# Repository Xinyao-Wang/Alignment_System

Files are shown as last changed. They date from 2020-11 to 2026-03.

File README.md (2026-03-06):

# Alignment System

Mechanical design project for a **laser alignment system** intended to precisely point a laser in a predetermined direction during assembly, with a removable adjustment mechanism and a locking mechanism to hold the final position. The repository currently contains four concept prototypes plus the final design report and presentation.

## Overview

This project was developed as **AS-1** for **ME175C**. The final design uses:

- a **two-axis adjustment mechanism**
- a **ball-joint-based fixing mechanism**
- **gear-driven angular adjustment**
- a **threaded-bolt mechanism** for controlled extension and shortening

The design targets precise manual alignment for applications where pointing accuracy matters, such as UAV-mounted systems and other directional devices.

## Design Requirements

The system was designed to satisfy the following requirements:

- **Adjustment range:** ±10°
- **Adjustment accuracy:** 0.2° to 0.4°
- **Mass:** under 500 g
- **Control dimensions:** 2-axis (roll and pitch)
- **Working temperature:** 0°C to 40°C
- **System size:** about 200–220 mm scale

These requirements and verification targets are documented in the final report and presentation.

## Final Design

The final concept combines an **adjustment mechanism** and a **fixing mechanism**:

- The **adjustment mechanism** uses an upper threaded adjustment path and a lower worm-gear path to control the laser orientation.
- The **fixing mechanism** uses a **ball joint** and locking structure to hold the aligned laser in place once adjustment is complete.
- After alignment, the adjustment structure can be removed while preserving the final laser direction.

## Verification Summary

The design was evaluated using **SolidWorks modeling** and **MATLAB analysis**.

### Accuracy
The report verifies that the design can achieve the required fine angular resolution, with estimated adjustment accuracy below **0.4°**, meeting the design target.

### Range of motion
The calculated movement range reaches about **10.36°**, satisfying the required **10°** alignment range.

## Repository Contents

This repository includes the following main items:

- `Prototype 1/`
- `Prototype 2/`
- `Prototype 3/`
- `Prototype 4/`
- `AS-1 Final Design Report.pdf`
- `AS-1 Final Presentation.pdf` 

## Design Process

Four concept directions were explored before selecting the final design:

1. detachable mechanical-arm-based alignment
2. double-gear alignment with fixture system
3. ball-joint platform with perpendicular link adjustments
4. three-bolt height-adjustment platform

A decision matrix was then used to compare concepts on criteria such as weight, simplicity, safety, efficiency, precision, and ease of operation.

## Manufacturing Notes

The project includes component-level design for manufacturability, with parts made from materials such as:

- acetal rod
- UHMW sheet
- mild steel
- standard mechanical hardware

Detailed part and assembly drawings are included in the final report appendix.

## Files

- **Final Design Report:** complete design description, requirements, concept evaluation, verification, MATLAB analysis, and drawings
- **Final Presentation:** concise summary of the project scope, concepts, final design, and validation
- **Prototype folders:** concept development files for the four design directions

## Tools Used

- **SolidWorks** for CAD modeling and design visualization
- **MATLAB** for range and adjustment analysis
- standard mechanical design and manufacturability methods based on the project workflow described in the report and presentation.

## Authors

- Dongwei Li
- Xinyao Wang
- Shi Cheng
- Deng Pan

## Course Information

**Course:** ME175C  
**Team:** AS-1  
**Project:** Alignment System  
**Date:** June 2020

## Notes

This repository serves as an archive of the project’s concept development, final design documentation, and presentation materials.

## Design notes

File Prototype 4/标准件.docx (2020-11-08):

蜗轮蜗杆：

https://www.ebay.com/itm/0-5-Modulus-20-to-60-Teeth-Worm-Gear-and-Shaft-Drive-Gearbox-Select-Size/302516360044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

涡轮：worm gear

https://www.mcmaster.com/57545K513

蜗杆：worm

https://www.mcmaster.com/57545K527

键：rounded machine key

https://www.mcmaster.com/95053A135

螺杆 screw

https://www.mcmaster.com/91310A151

螺帽 nut

https://www.mcmaster.com/90592A034

底座固定螺栓 screw

https://www.mcmaster.com/91310A332

底座柱固定螺栓

https://www.mcmaster.com/91310A332

球关节 ball knob

https://www.mcmaster.com/6045K32

球关节螺栓 screw

https://www.mcmaster.com/92620A204

中间棒 rod /导轨杆

https://www.mcmaster.com/8497K371

轴承 ball bearing

https://www.mcmaster.com/5972K91

上面的外壳 steel round tube

https://www.mcmaster.com/7767t271

导轨螺栓 socket head screw

https://www.mcmaster.com/90332A112

导轨螺帽 nut

https://www.mcmaster.com/96537A120

底板

https://www.mcmaster.com/4296A28

套筒组件螺栓

https://www.mcmaster.com/91290A231

卡簧

https://www.mcmaster.com/97431A310

内垫圈

https://www.mcmaster.com/90214A518

外垫片

https://www.mcmaster.com/90214A536

弹簧

https://www.mcmaster.com/9657K424

缓冲垫片

https://www.mcmaster.com/93650A110

金属垫圈

https://www.mcmaster.com/92141A009

peel shim

https://www.mcmaster.com/9574K76-9574K76

Base Adjustment Bolt Nut

https://www.mcmaster.com/96194A101

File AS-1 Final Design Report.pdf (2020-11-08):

AS-1

## THE DESIGN OF LASER ALIGNMENT SYSTEM

Dongwei Li, Xinyao Wang, Shi Cheng, Deng Pan

Course Number: ME175C

Team Number: AS-1

Instructor: Prof. Dinsmore

Project: Alignment System

Date: 06/08/2020

Executive Summary

In some specific situations, such as distant communications or UAV precise

positioning. Antenna or other related devices itself should be positioned precisely to reduce

the final total error of the product. So, our goal is to design and construct a device which

will allow a laser to be precisely adjusted to an UAV in the process of assemble and, once

it is in the final position, will hold the laser in place. We design a device which can rotate

the adjusting bolts to control the threaded rod to achieve our requirements. We first

determine the system’s some of the most basic requirements, through several iterations, we

get the current model, then verified the device’s adjustment accuracy and range by

modeling and analysis by Solidworks and MATLAB. Up to now, we have completed all

the design process. Under the assumption that the minimum adjustment angle of hand is 4

degree, we get the result that the accuracy is between 0.2-0.4 degree, which meets the

requirement we set.

Table of Contents

### 4.1 The Input, Output and Parameters set by our Simplified Model……11

### 1. Introduction

Alignment systems are widely used, from Mars probes to drones. Because of the

highly directional nature of these high-performance systems, even small misalignments in

the system can prevent the receiver from seeing the signal. Our goal is to design and

construct a device which will allow a laser to be precisely adjusted to an UAV in the

process of assemble and, once it is in the final position, will hold the laser in place. We set

the adjustment range is 10°, adjustment accuracy is 0.3°, two axis control and total mass

less than 500g. In this article, we introduce the detailed device information, demonstration

process, model building and validation and detailed component and assembly drawings.

### 2. Problem Statement

Alignment systems are widely used, from Mars probes to drones. It is especially

important to precisely align the interface and related fixtures. Our group mainly considers

the alignment system to fix a laser pen on the joint surface and point it in any predetermined

direction.

### 2.1 System Requirements

In order to increase generality, we set our system’s size about 200mm, and because

of our project is a high precision device, we consider the adjustment range and accuracy

are the main requirements of our design, thus we set the adjustment range is 20°, adjustment

accuracy is about 0.2°---0.4°. In order to reduce the impact on the performance of the drone

and increase reliability, we decide the fixing system total mass is less than 500g. Our main

task is to control its pointing direction; thus, the effect of laser pen rotate around the long

axis can be ignored.

### 3. Design Solution

The mechanical structure we finally designed consists of two parts, adjusting

mechanism and fixing mechanism (Fig. 1).

Adjustment range | ±10°
Adjustment accuracy | 0.2°~0.4°
System mass | <500g
System size | ≈200mm
Working temperature | 0℃-40℃
Control dimensions | 2-axis (roll pitch)

Table.1 System requirements

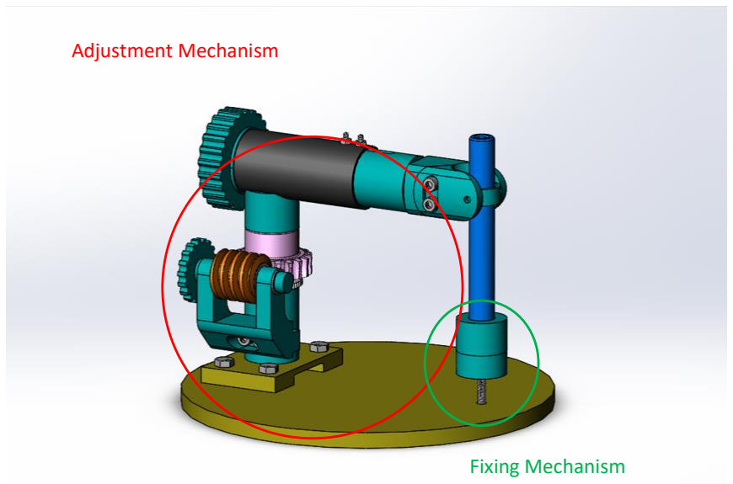
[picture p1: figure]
Adjustment Mechanism; Fixing Mechanism

Fig. 1 Adjustment mechanism and Fixing mechanism

### 3.1 Adjustment Mechanism

The Fig. 2 shows the name of key components, an adjusting bolt and threaded nut

are to control the vertical extension and shortening of the robot arm. Another adjusting bolt

and worm also have gear to control the rotation of the robot arm in the horizontal direction.

The sleeve could move along the laser pen and rotate to satisfy any angle, so that these two

bolts could control the laser pen move in a fan-shaped plane, and point to any point in this

area.

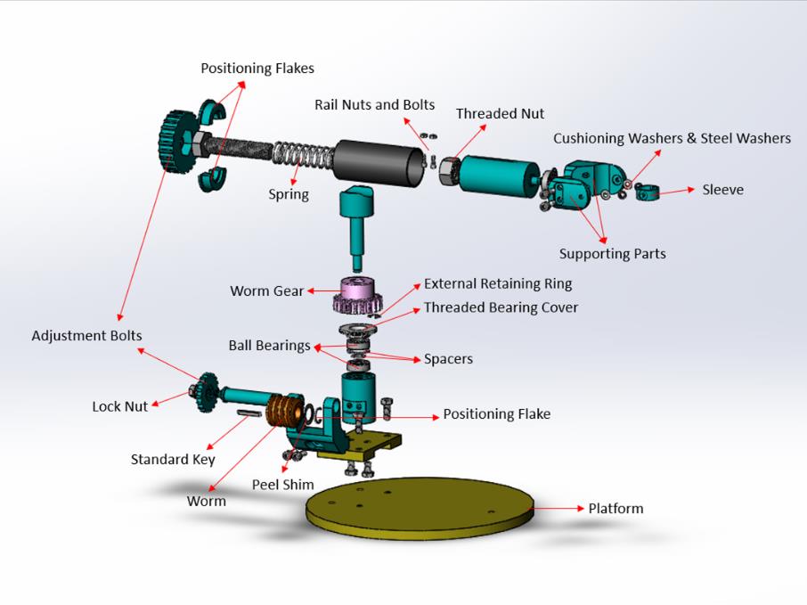
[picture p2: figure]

Fig. 2 Key components of adjustment mechanism

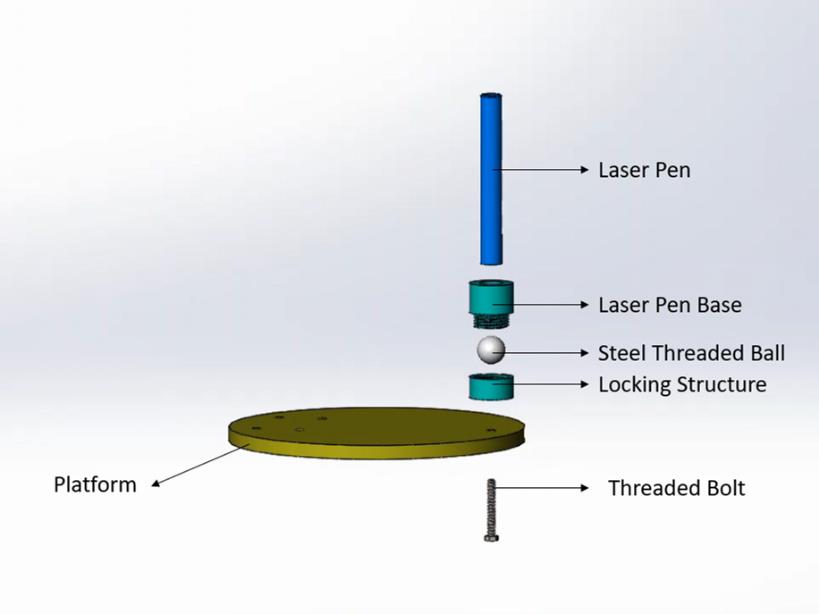
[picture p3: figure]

Fig. 3 Components of fixing mechanism

### 3.2 Fixing Mechanism

The fixing mechanism is mainly composed of steel ball, locking structure, threaded

bolt, as shown in Fig. 3. And the threaded bolt is used to fix the ball joint on the platform,

the structure is similar to the ball joint on tripod and phone holder on vehicle, a high friction

will be produced by pressure, and stable fix the ball joint.

The operator only needs to handle these two adjustment bolts to adjust the

mechanical arm to extend or shorten in vertical direction and to rotate the mechanical arm

in the horizontal direction. The movement of the laser is driven by the movement of the

mechanical arm. When moving to the specified position, user can tighten the ball joint to

fix it. Finally, we will dismantle the adjustment mechanism and keep aligned laser.

### 3.3 Function and Material of Components

Some of the parts that make up our mechanical device are standard parts purchased

directly. What we introduce below are that we need to purchase materials and manufacture.

The parts in Figures 4 to 17 are made by Acetal Rod. They are manufactured by

CNC milling machine and CNC lathe according to the parts drawing. The holes on the

parts can be drilled directly by laser drilling technology or punching machine.

Adjustment knob is a handle part to fix the bolt into its hexagon hole; the base

adjustment knob is also a handle part for worm and worm gear, it could be threaded into

the rod and fixed by locking nut; the base adjustment rod could connect knob and worm,

there are two way threads: left and right, which could ensure the locking nut will not fall

off after adjustment.

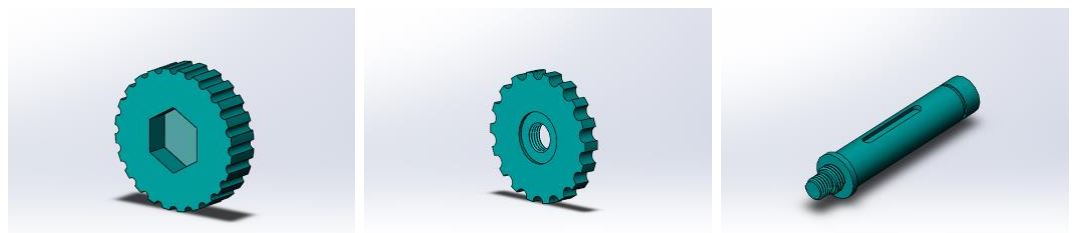
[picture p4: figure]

Fig. 4 Adjustment knob | Fig. 5 Base adjustment knob | Fig. 6 Base adjustment rod

Base rod is a basic part, which could connect base, top parts and worm part, there

are four threaded holes and a deep hole for two ball bearings; laser pen base could hold the

laser pen and the threaded ball, it could work with the nut for threaded ball together to

produce enough friction to fix the ball joint.

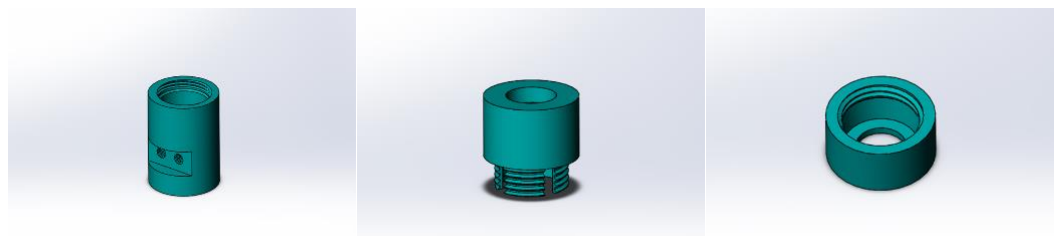
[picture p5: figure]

Positioning flake is a supporting part for adjustment bolt, two flakes could limit the

axial movement of bolt during the adjustment, and another step could support the spring;

the rail rod is working as a mechanical arm, which could fix the adjustment nut into its

hexagon hole, and the groove could limit the rotation during the adjustment, on the other

side, the small rod could fix the ball bearing and support the sleeve part; the supporting rod

for shell is a supporting part to connect base rod and shell.

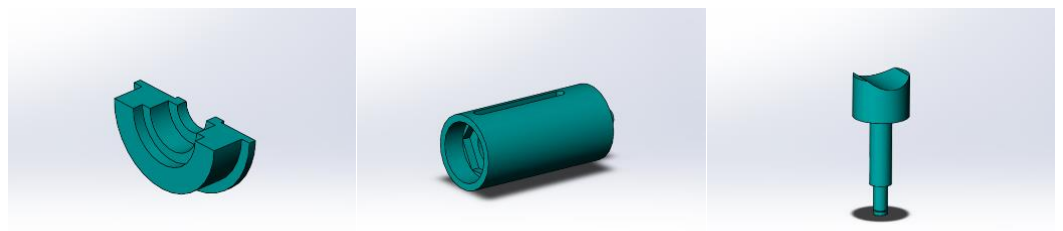
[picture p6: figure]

These three are components of sleeve parts: two supporting parts and a sleeve. The

supporting parts could contain a ball bearing which could provide low friction during

rotation, and also could hold the sleeve and ensure its movement; the sleeve has three

“points” to reduce friction between laser pen.

Fig. 7 Base rod | Fig. 8 Laser pen base | Fig. 9 Nut for threaded ball
Fig. 10 Positioning flake | Fig. 11 Rail rod | Fig. 12 supporting rod for shell

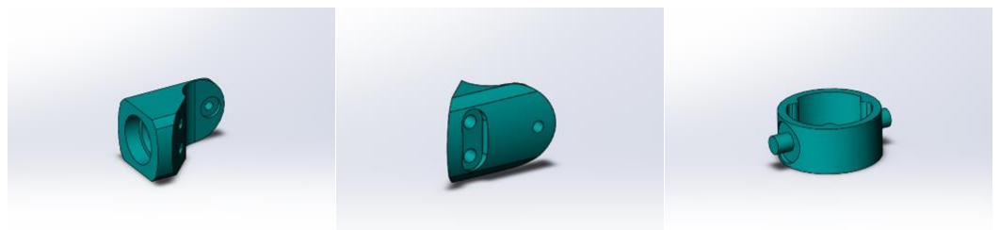
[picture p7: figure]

The supporting part for worm could be fixed on the base rod by two screws, and it

could support the worm and provide enough force to avoid movement during adjustment;

the threaded bearing cover could be threaded into the base rod, and fix the outer ring of the

top ball bearing to avoid loosening.

The parts in Fig. 18 and Fig. 19 are made of Slippery Black UHMW Sheet. They

are punched with a punching machine after being processed by a lathe. The base is a

connecting part to connect base rod and platform, which has six holes for screws, two are

to fix rod, four are to fix the platform; the platform is the supporting part for the adjustment

mechanism and the fixing mechanism, they will be fixed on it and cooperate.

Fig. 13 Supporting part 1 | Fig. 14 Supporting part 2 | Fig. 15 Sleeve

Fig. 16 Supporting part for worm

Fig. 17 Threaded
bearing cover

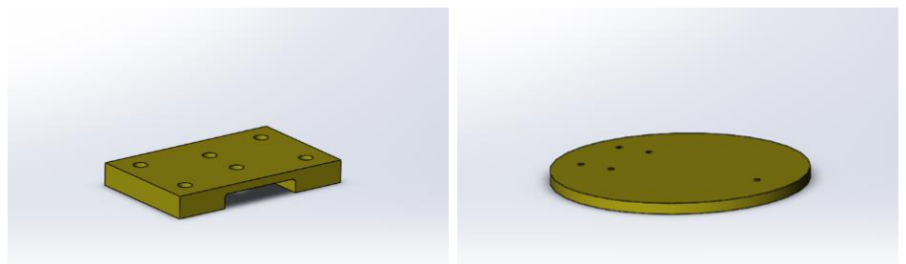
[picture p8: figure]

Fig. 18 Base | Fig. 19 Platform

The part shown Fig. 20 is made of mild steel. Just use a milling machine to make

two holes on the cylindrical material into the part shown on the CNC lathe. The shell is a

supporting part to hold rail rod and the bolt, the two holes are for rail screws and nuts, they

could be fixed into holes and work as guides.

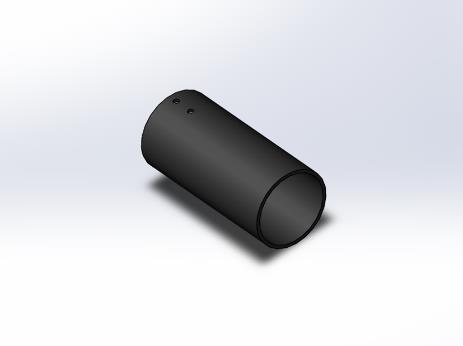
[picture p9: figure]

### 4. Design Verification

The purpose of our virtual prototype is to show the parts intuitively and omit the

shapes and dimensions that have no influence on the calculation. In the simplified model,

we only keep two pairs of gears, laser pen and necessary rotating parts. We use the center

point of the contact position between the sleeve and the laser pen to represent the laser

coordinates. It is used to analyze and verify whether (1) the accuracy and (2) the range of

the adjustment system designed by us meet the requirements. The position change of the

center point and the angle change of the laser pointer relative to the vertical state when the

two gears rotate respectively are calculated by MATLAB, which is used to check our

design.

Fig. 20 Shell

First, Fig. 21 shows our adjustment range. The shadow part represents the

maximum moving range of laser in our system. The range included in the circle represents

the range of movement we require.

### 4.1 The Input, Output and Parameters set by our Simplified Model

Fig. 22 and Fig. 23 show the radius parameters of the moving range and the actual

required range of the manipulator. Fig. 24 shows the length change of the manipulator.

And then we get:

Parameter (1): Radius of laser pen center (r): 16.75 mm

Parameter (2): Radius range of the system(R): 17.35 mm

Input (1): Change range of arm length(b): -17.35mm~17.35 mm

Fig. 21 Movement range

Fig. 22 Designed range | Fig. 23 Actual range | Fig. 24 Length variation of mechanical arm

Fig. 25 and Fig. 26 show the deflection angle of our robot arm and the deflection

angle of the laser pen based on the reference plane and line.

And then we get:

Parameter (3): Angle range of the system: -30°~30°

Parameter (4): Expected adjustment angle of laser pen: -10°~10°

Input (2): Angle range of the system(a): -30°~30°

Output (1): Deflection angle of laser pen(c): The value range of c should be greater than

be larger than -10°~10°

Fig. 27 shows the simplified length parameter of the part, which is convenient for

us to establish the coordinate system and other calculation and checking in the future.

And then we get:

Fig. 27 The simplified length parameter of the part

Fig. 25 Deflection angle of mechanical arm

Fig. 26 Deflection angle of laser pen

Parameter (5): Height from the Rod to the Ball Joint (H): 95 mm

Parameter (6): Radius from the base center to the pen (L): 140 mm

### 4.2 Verification of Adjustment Accuracy

First, as shown in Fig. 28, we divide our adjustment system into two parts: Part A

and Part B.

We need to adjust the gears in part a and part B respectively to adjust the deflection

range of the laser pen. Because the power of this structure is hand, it is hard to calculate

the accuracy of this system. Here we assume the minimum adjustment angle of hand is 4°.

The adjustment accuracy in part A is shown in Fig. 29.

Pitch of the Higher Adjusting Bolt: 2mm

Fig. 28 Divided adjustment system

Fig. 29 Part A

Minimum Adjustment Length of R: 2mm × (4°/360°) = 0.0222mm

Minimum Adjustment Angle of Bolt:

θ1 = 10° − arctan(

16.75 − 0.0222
95 ) = 0.0136°

θ2 = arctan(

0.0222
95 ) = 0.0134°

The adjustment accuracy in part B is shown in Fig. 30.

Speed Ratio: 20:1

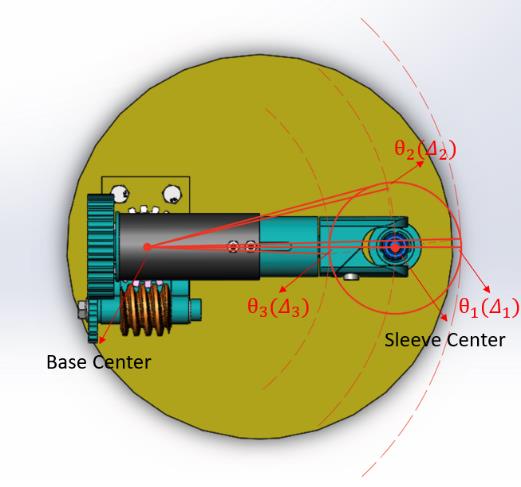
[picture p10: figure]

Angle per Pitch of the Worm Gear: 360°/20 = 18°

Worm Gear Minimum Rotation angle: 18° × (4°/360°) = 0.2°

Adjustment Angle of the Lower Gear: 0.18°

Minimum Adjustment Angle of Worm Gear:

√H² + R² = 96.47mm | (1)

Δ1 = (

0.2
360) × 2π(L + R) = 0.547mm | (2)

θ1 = arcsin (

0.547
96.47) = 0.325° | (3)

Δ2 ≈ (

0.2
360) × 2πL = 0.489mm | (4)

Fig. 30 Part B

θ2 = 10° − arctan(

16.75−0.489
95
) = 0.287 | (5)

Δ3 = (

0.2
360) × 2π(L − R) = 0.430mm | (6)

θ3 = arcsin (

0.430
96.47) = 0.256° | (7)

In part A and part B, our adjustment accuracy is less than 0.4°. And the adjustment

accuracy can meet our design requirement.

### 4.3 Verification of the Range of the Adjustment mechanism

Create a rectangular coordinate system, Fig. 31 as shown.

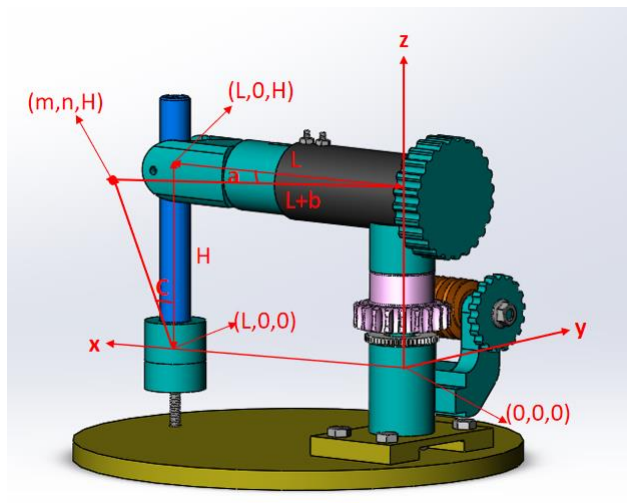
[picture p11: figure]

The center of the sleeve represents the position of the infrared light of the laser. The

initial coordinate is (L, 0, H). The changed coordinate of the laser adjusted to the specified

position is (m, n, H), and the deflection angle of the laser is c. The length of the manipulator

is L + b, and the deflection angle is a. Hence (m - L) is the change of x -coordinate and n

is the change of y-coordinate. And we can get：

m = (L + b) × cos(a); | (8)

Fig. 31 Coordinate system

n = (L + b) × sin(a); | (9)

c can be regarded as the angle between vector (m-L, n, H) and vector (0,0,1), then:

c = acos(

H
√(m−L)
2 | 2+n²+H²
); | (10)

Put in the parameters we set, corresponding to this part of the code in MATLAB,

as Fig. 32 shown.

Minimum Adjustment Length of R: 2mm × (4°/360°) = 0.0222mm

Worm Gear Minimum Rotation angle: 18° × (4°/360°) = 0.2°

Input(a): Angle range of the system: -30°—30°, unit angle:0.2°

Input(b): Change range of arm length: -17.35mm—17.35 mm unit length:0.0222mm

Then corresponding to this part of the code in MATLAB, Fig. 33 as shown.

In addition, substituting the input we set, Fig. 34 and 35 show the input data of a

and b.

Fig. 34 Input value of a

Fig. 32 Relational MATLAB code

Fig. 33 Input MATLAB code

a and b meet our input requirements. Finally, we take a, b as the input, m, n, c as

the output, and draw their images respectively, as Fig. 36, 37 and 38 shown. By observing

their images, we can get our range of motion.

Fig. 35 Input value of b

Fig. 36 Change of the reference point on the x-axis

Fig. 37 Change of the reference point on the y-axis

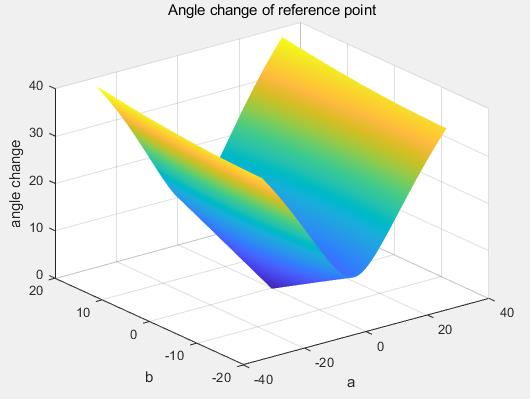
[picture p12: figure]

Fig. 38 Angel Change of the reference point

From figures above, we can see that the adjustment range (angle change) is about

10.36°, in the definition report, we set the requirement is 10°, thus the adjustment range

can meet our design requirement.

### 5. Approach to Solution

We first determine the system some of the most basic requirements, such as the

need to easy operation, simple structure and regulating mechanism can be removed, and

the method of using the 4-3-5, after the brainstorming, we finally came up with the total 4

kinds of structures.

### 5.1 Concept 1

The concept 1 has a detachable mechanical arm mounted on the joint surface (Fig.

39). It uses two bearings that are vertical in space to orient the alignment device’s direction.

If we fix the component on the mount surface directly, we cannot adjust its direction

conveniently. Therefore, a spherical pair is used to fix its position and adjust its direction

at the same time. On the adjusting device we extend the adjusting lever to get better

accuracy. In this solution, we can control the three supporting rods’ angles to make the

component point at presupposed direction. After the adjustment is completed, turn the

screws on the spherical pair to increase friction force between the shell and the ball. This

Fig. 39 Gear adjustment will fix it to point at the goal. Then remove the arm from mount surface to reduce the

weight of UAV.

### 5.2 Concept 2

The concept 2 is constructed with double-gear system as the alignment system and

connecting rod system as the fixture system (Fig. 40). For the alignment system, all the

components are connected with the frame while the frame is fixing on the UAV mount

with four bolts. By turning two meshing gears, the angles of x-z axis and y-z axis can be

changed to alignment. Using gears of different transmission ratios, the accuracy of angle

changing is determined and adjustable. For the fixture system, four rotating rods will allow

the angle changing of the laser and by fastening the screws of the joints and releasing the

buckle, the laser will be fixed after alignment.

### 5.3 Concept 3

The concept 3 has two platforms the UAV platform and the platform on which the

laser is placed are linked by a ball joint (Fig. 41, Fig. 42), which can ensure that the distance

between the centers of the two platforms remains the same, so that only the laser angle is

changed without changing the spatial position. Two four-strait structures are connected to

the laser platform perpendicularly to each other, and two joysticks are extended. First,

Fig. 40 Robotic arm adjustment adjust the two extending joysticks to adjust the vertical and horizontal rotations. After the

adjustment is completed, tighten the joint by tightening the ball joint nut, and use the

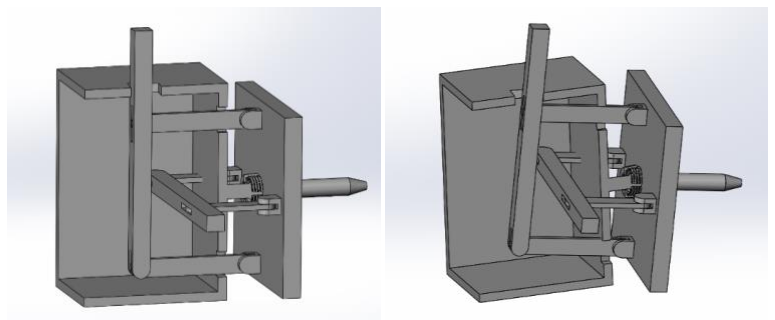
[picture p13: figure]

friction to fix the UAV platform and the laser platform.

### 5.4 Concept 4

The concept 4 is as shown in Fig. 43 and Fig. 44. Three bolt columns are fixed on

the surface of the UAV and pass through the sleeve on the plane equipped with laser. By

rotating the bolt, the three sleeves can move up and down in the vertical direction. The

three bolts are connected with the laser platform through the spherical joint, and three

sliders with an angle of 120 degrees are added into the laser platform to adapt to the

distance change between the platform and the bolts when the platform rotates. Therefore,

we can adjust the position of the triangle accurately by rotating three nuts to adjust the laser

direction.

Fig. 41 View 1 adjustment by 4 links | Fig. 42 View 2 adjustment by 4 links
Fig. 43 View 1 Height adjustment method | Fig. 44 View 2 Height adjustment method

### 5.5 Final Prototype

Finally, we used the decision matrices to evaluate whether these four systems meet

our requirements, including light weight, easy to operate, safe, simple structure, high

efficiency, and so on. The scoring content and results are shown in Table. 2.

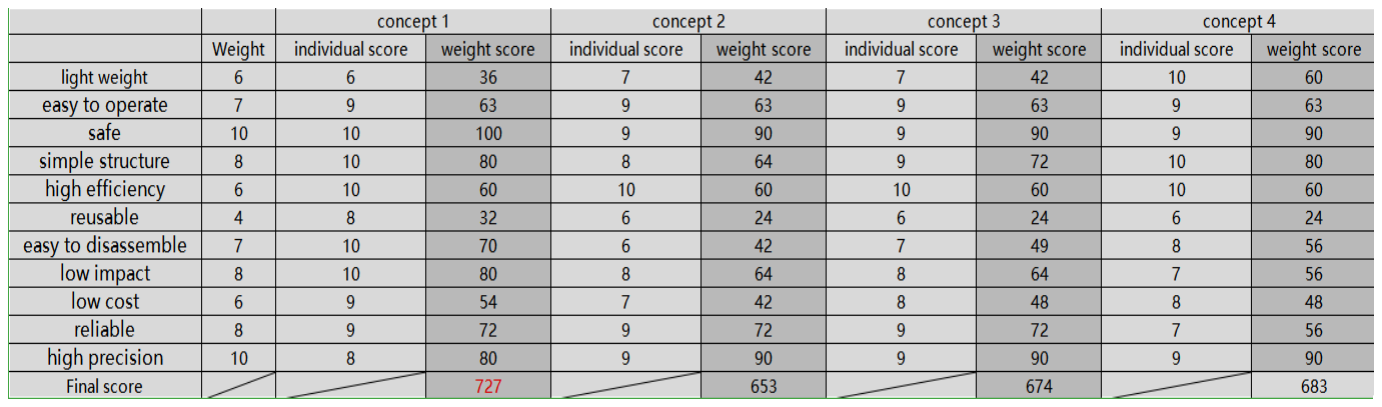
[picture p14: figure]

In the end, we get multiple designs to get the final design (Fig. 45), which is a

prototype to show our thoughts and the theory we used, so it is a little bit different from

the final design. It is easy to disassemble, easy to adjust and relatively simple in structure.

1. Laser movement controlled by robotic arm fixture
2. Fixing laser with ball joint
3. Gears can be used to control robotic arm deflection
4. We can use the bolt thread to control the elongation and shortening of the arm

Table.2 Decision matrices

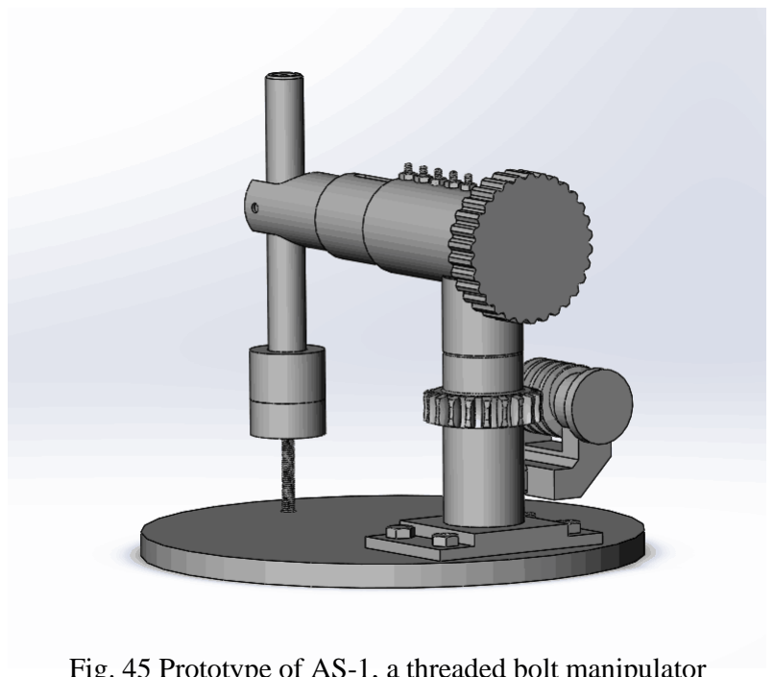
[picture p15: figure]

Fig. 45 Prototype of AS-1, a threaded bolt manipulator

It fully meets the specifications of the problem statement. As well it is easy to

manufacture.

### 6. Conclusions and Recommendations

So far, the proposed design meets all the requirements in the problem definition

and it is the most optimum plan considering the cost, the materials, and other aspects in

this project. However, if there is another project with different requirements or there are

better choices of the materials found, here are the recommendations.

For the design of the adjusting bolt, since the low yield of the alignment systems,

step cut will make sure the high precision which is applied in this project.

Once it comes to special cases that the yield become high, considering the cost of

step cut, washers should be the better choice which can fit the basic function of reducing

connecting area and save much money as well. But the precision will be lower than our

design

For the design of the supporting part, if there are screws with high friction or more

reliable design, the number of screws can be reduced by one.

## References

Appendices

MATLAB code:

clear

clear all

x=linspace(-30,30,241);

y=linspace(-17.35,17.35,1249);

[X,Y] = meshgrid(x,y);

m=(140+Y).*cos(X/180*pi);

n=(140+Y).*sin(X/180*pi);

k=m-140;

Z=acos(95./sqrt(k.*k+n.*n+95^2))*180/pi;

Z=real(Z);

figure(1),mesh(X,Y,Z),view(3)

title('Angle change of reference point')

xlabel('x')

ylabel('y')

zlabel('angle change')

figure(2),mesh(X,Y,m),view(3)

title('Change of the reference point on the x-axis')

xlabel('x')

ylabel('y')

zlabel('Changes on x axis')

figure(3),mesh(X,Y,n),view(3)

title('Change of the reference point on the y-axis')

xlabel('x')

ylabel('y')

zlabel('Changes on y axis')

Part and Assembly Drawings

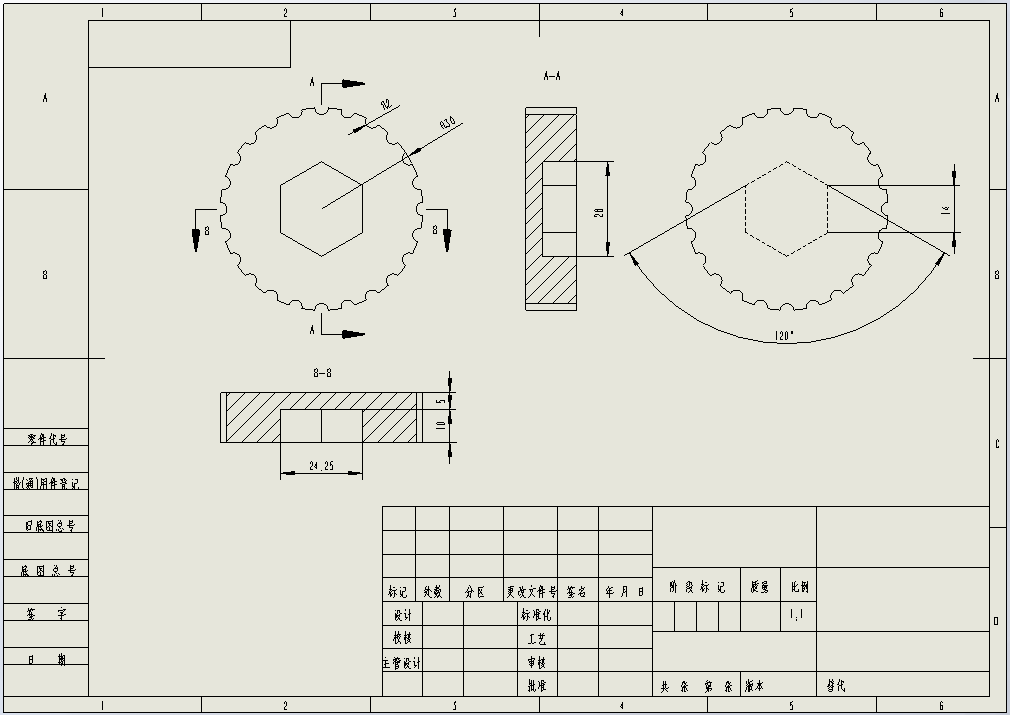
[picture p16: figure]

Fig. 46 the part drawing of adjusting knob

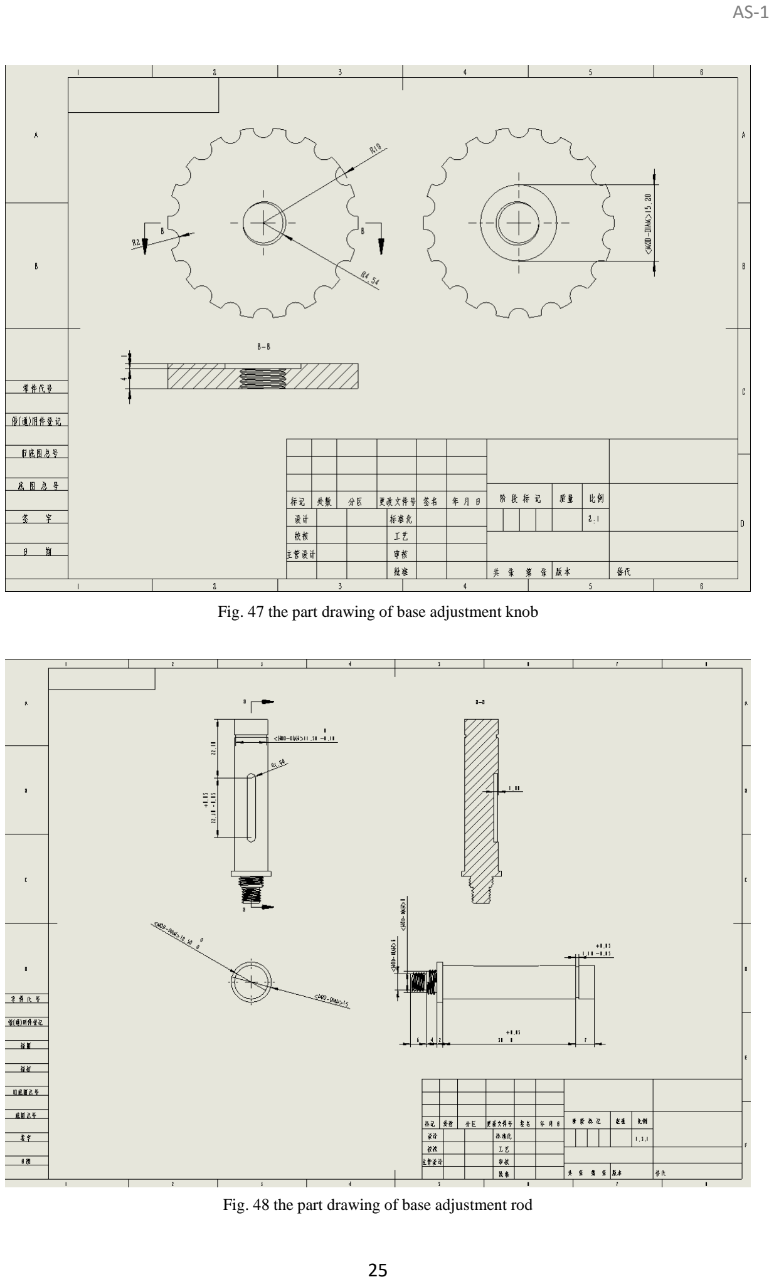
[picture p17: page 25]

Fig. 48 the part drawing of base adjustment rod

Fig. 47 the part drawing of base adjustment knob

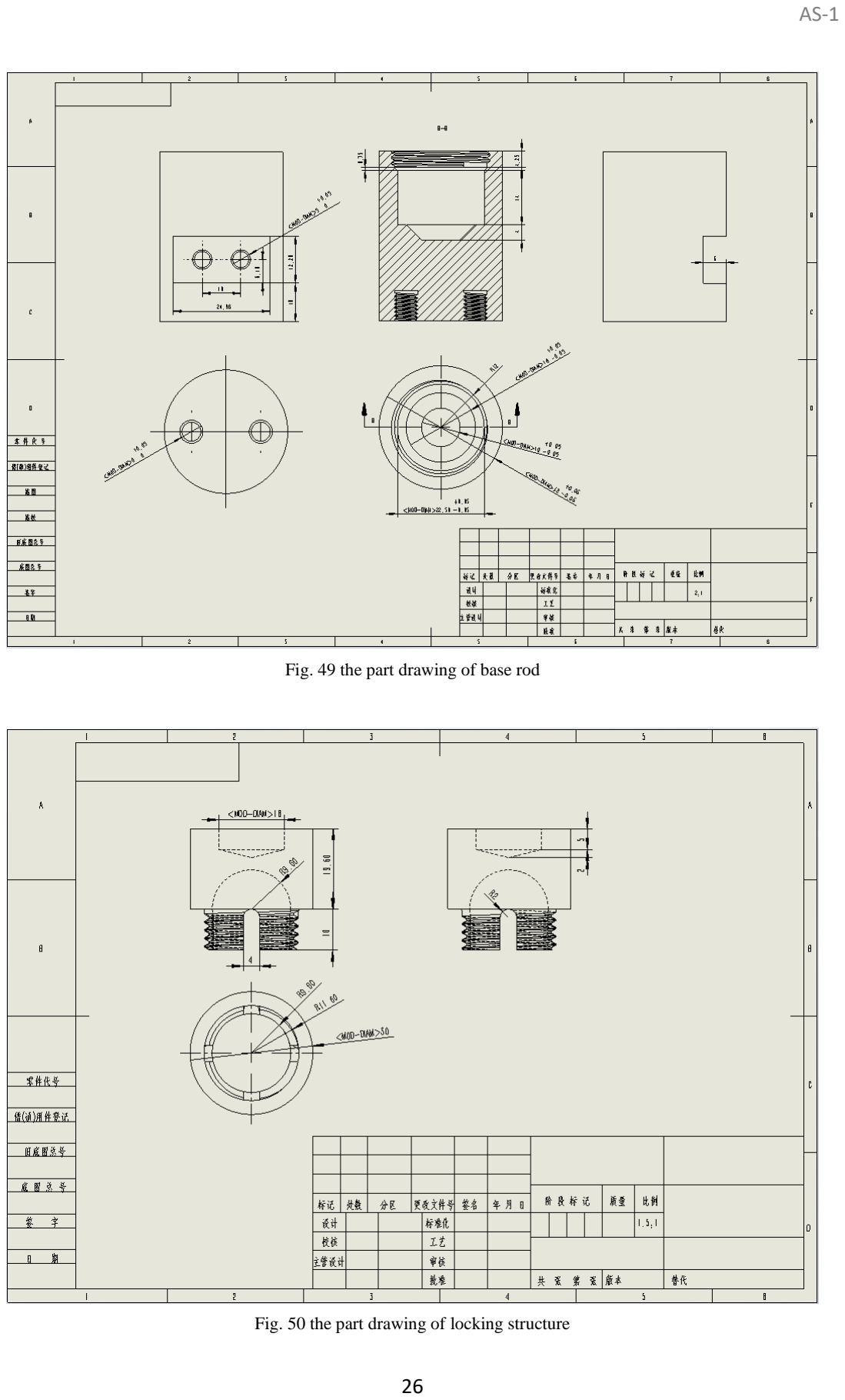
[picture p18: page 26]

Fig. 49 the part drawing of base rod

Fig. 50 the part drawing of locking structure

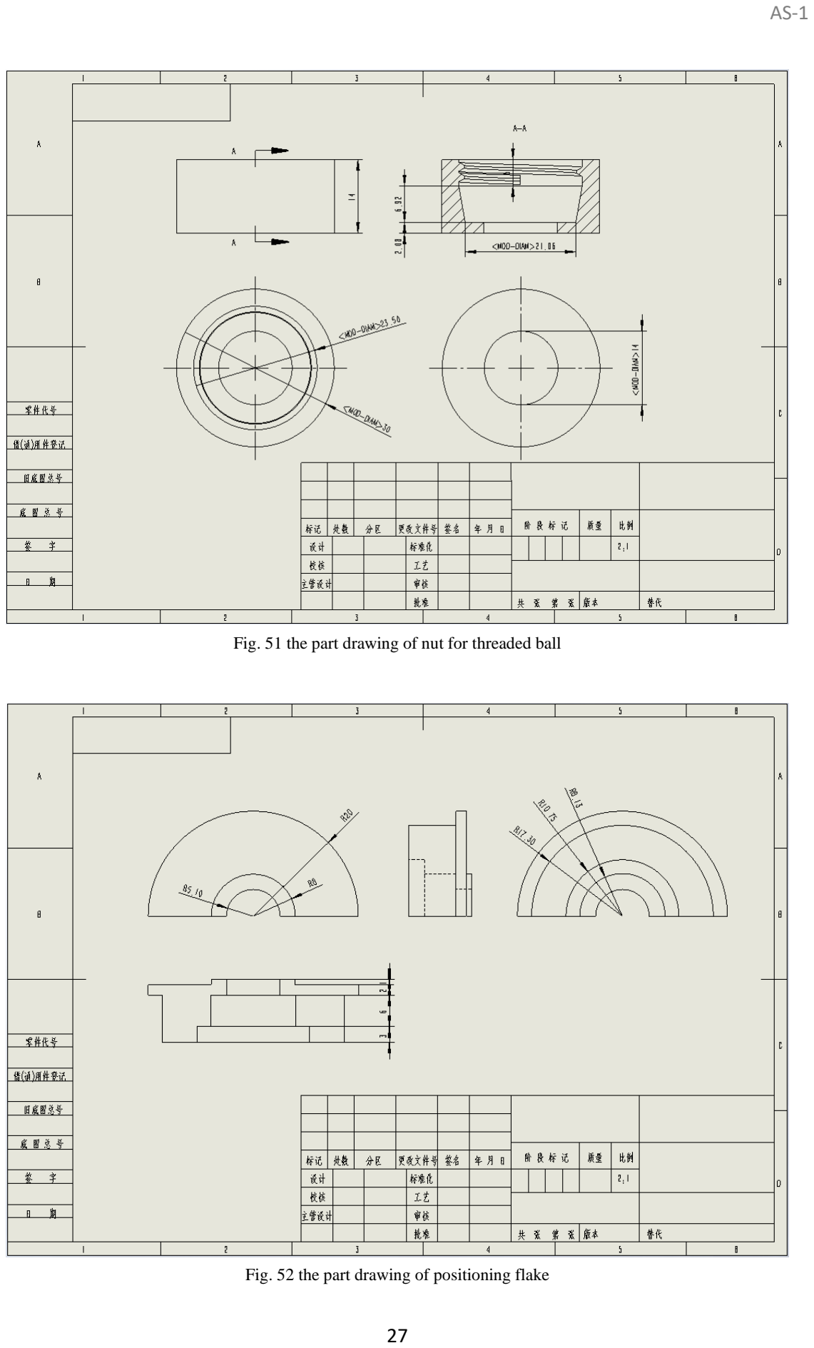
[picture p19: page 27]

Fig. 51 the part drawing of nut for threaded ball

Fig. 52 the part drawing of positioning flake

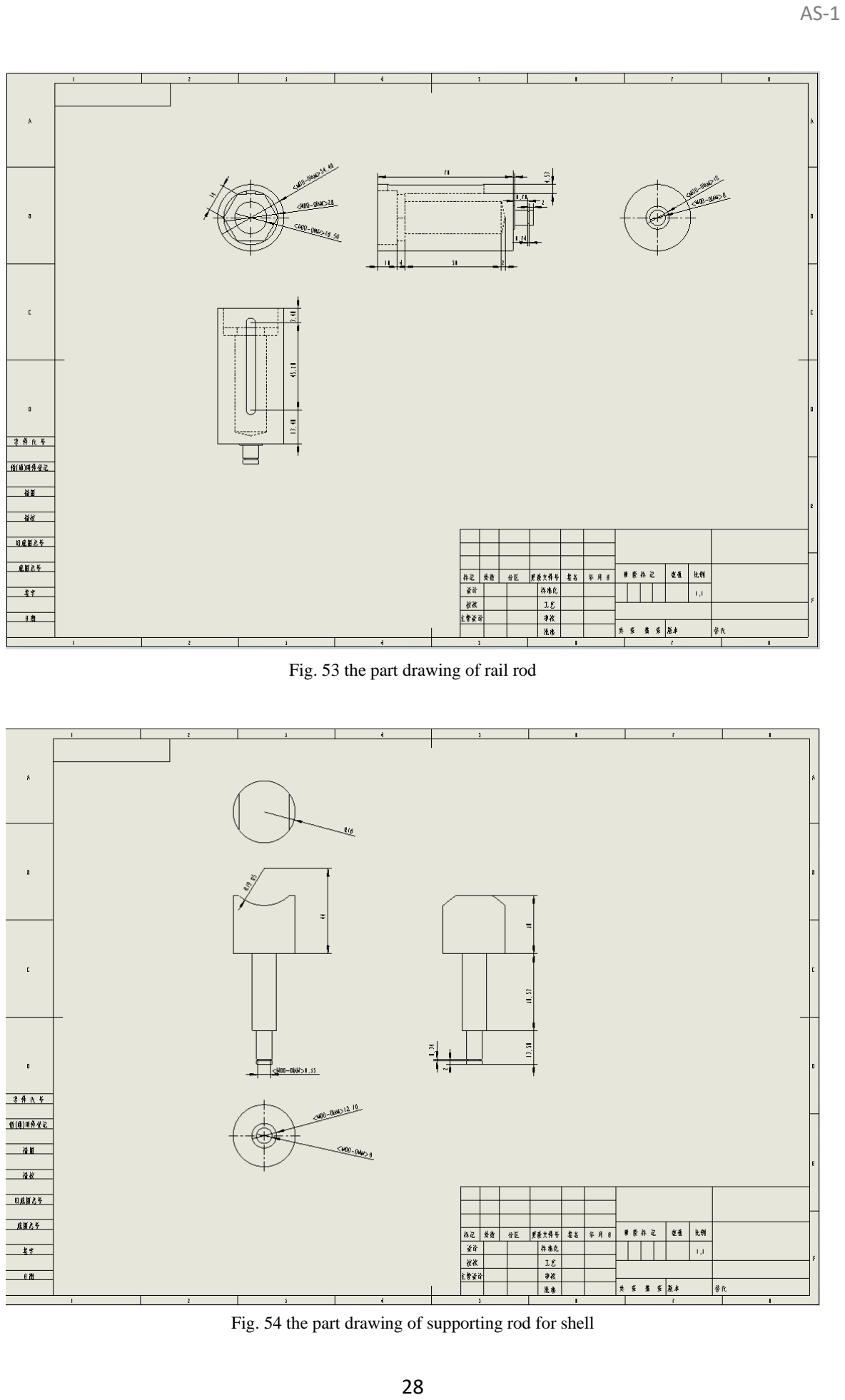
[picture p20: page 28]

Fig. 54 the part drawing of supporting rod for shell

Fig. 53 the part drawing of rail rod

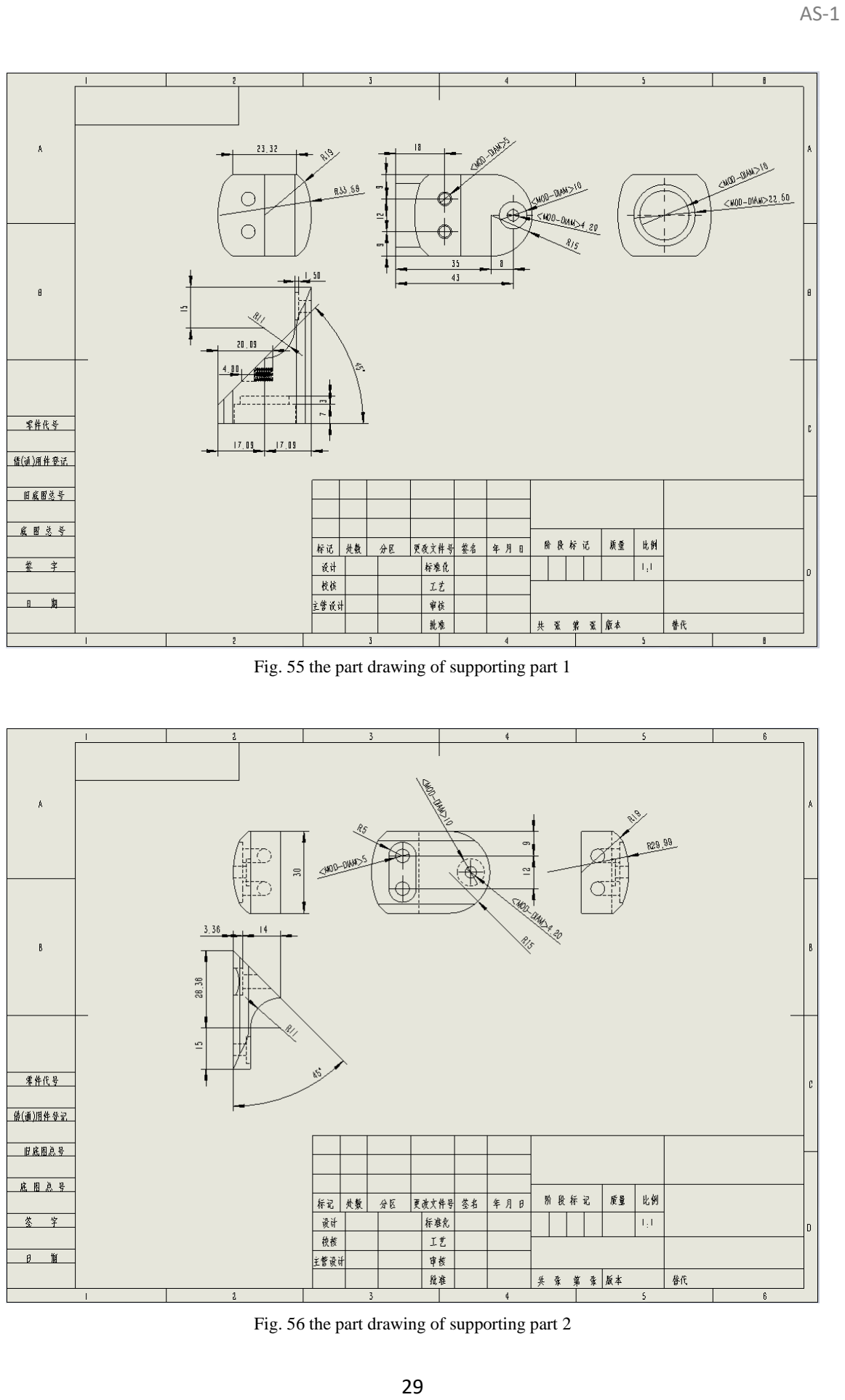
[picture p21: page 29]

Fig. 55 the part drawing of supporting part 1

Fig. 56 the part drawing of supporting part 2

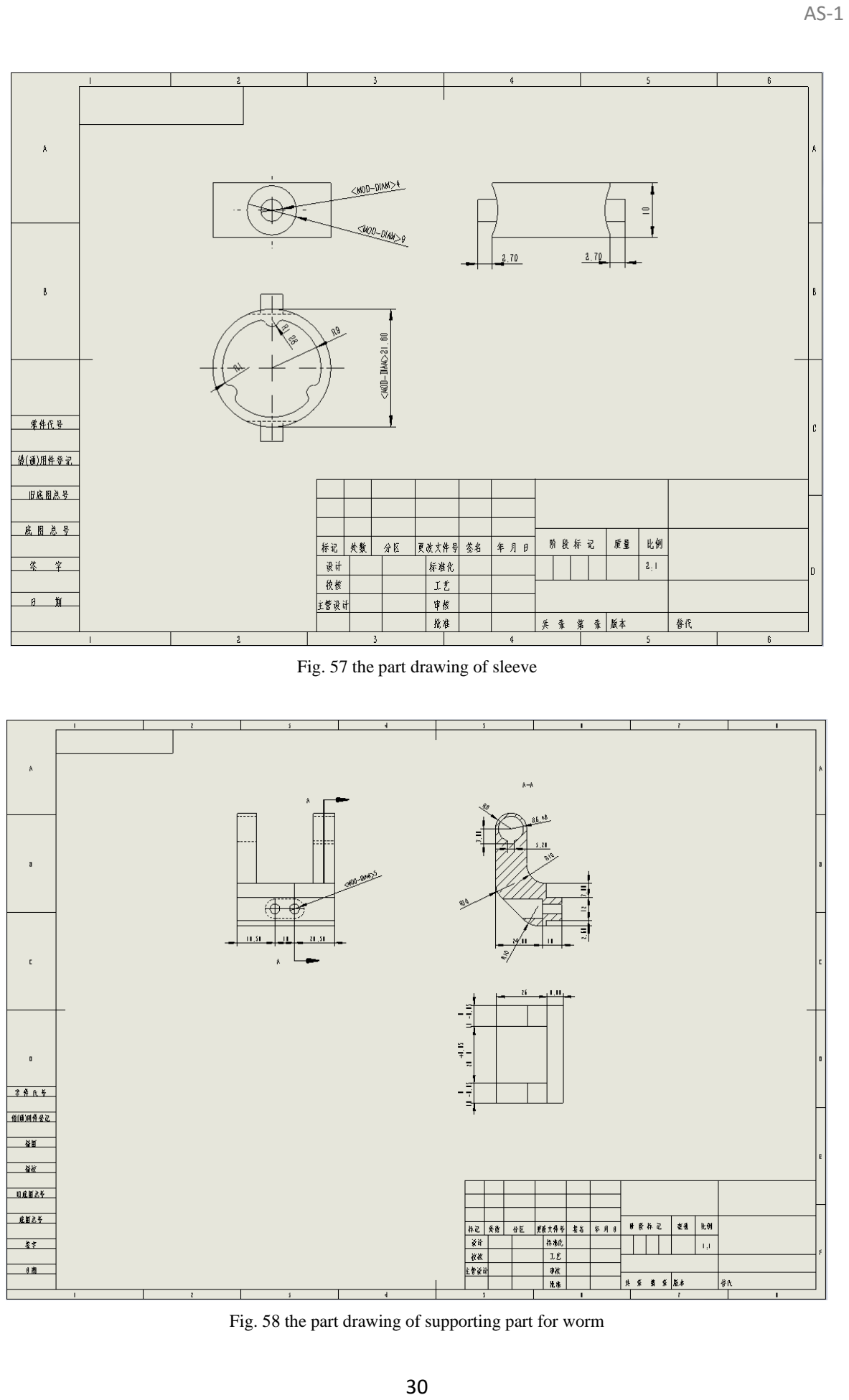
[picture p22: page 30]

Fig. 57 the part drawing of sleeve

Fig. 58 the part drawing of supporting part for worm

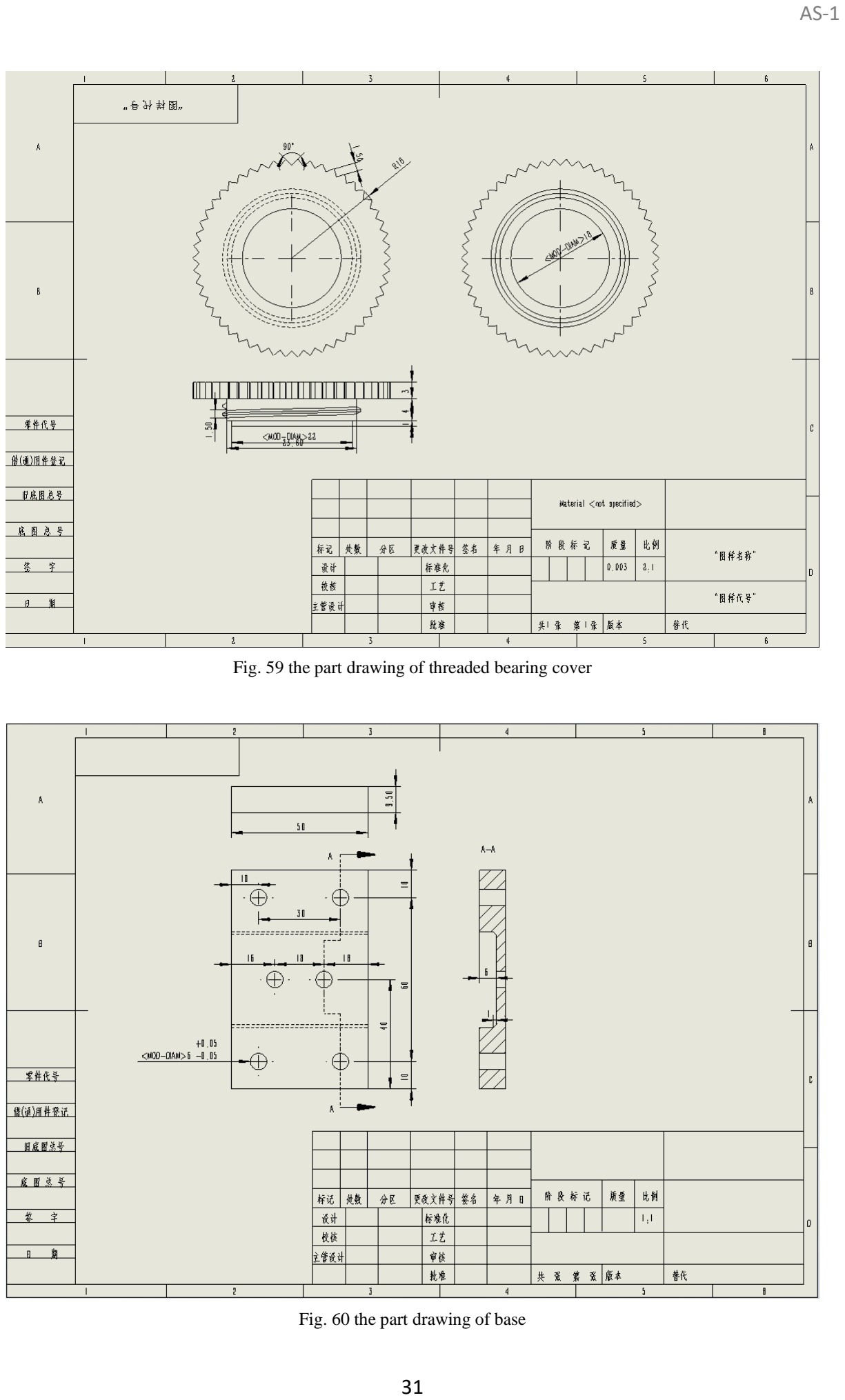
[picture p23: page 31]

Fig. 59 the part drawing of threaded bearing cover

Fig. 60 the part drawing of base

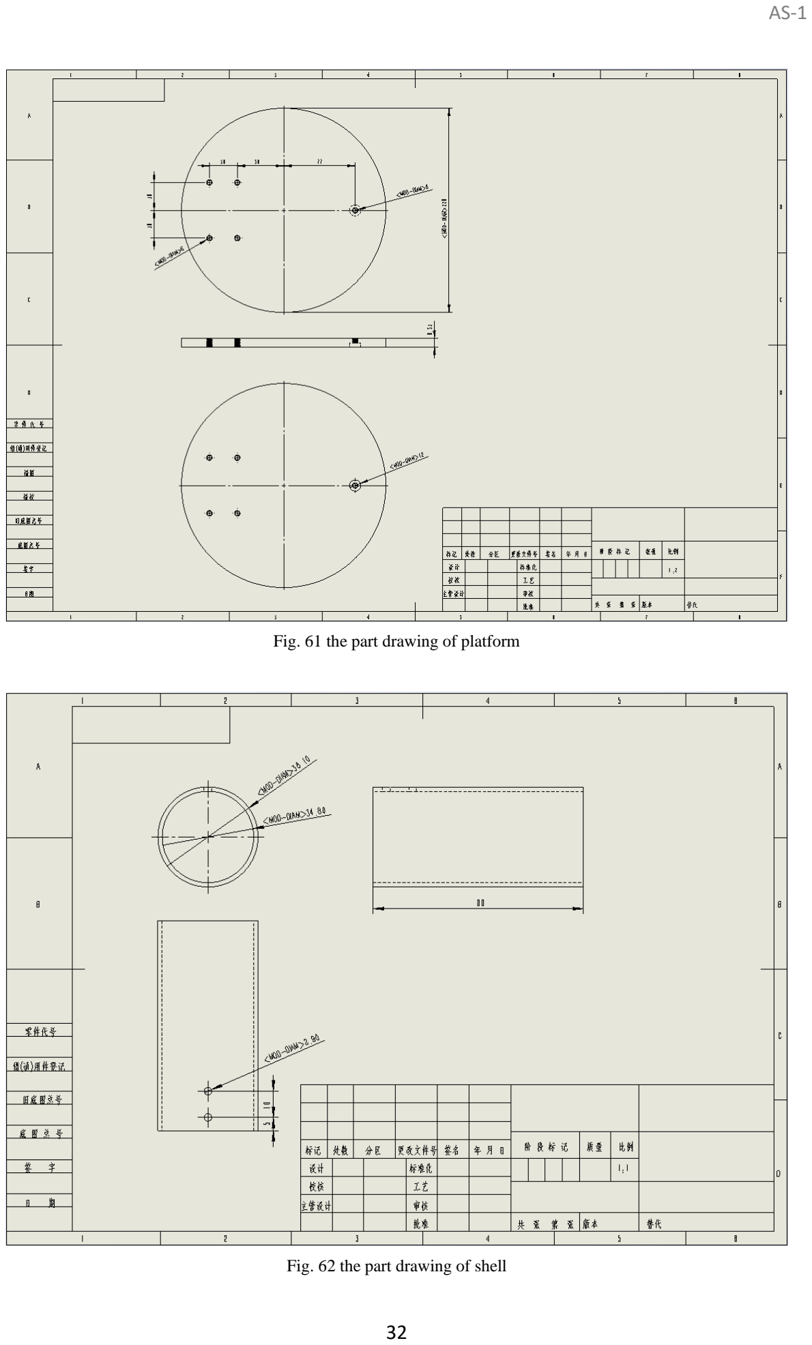
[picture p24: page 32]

Fig. 61 the part drawing of platform

Fig. 62 the part drawing of shell

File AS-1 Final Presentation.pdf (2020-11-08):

# THE DESIGN OF

# LASER ALIGNMENT SYSTEM

June 1st , 2020

Xinyao Wang, DongWei Li, Shi Cheng, Deng Pan

# AS-1 Final Presentation

# Problem Statement


Alignment systems are widely used, from Mars probes to drones. It is especially important to precisely align the interface and related fixtures. My group mainly considers the alignment system to fix a laser pen on the joint surface and point it in any predetermined direction

Mars rover mines rock samples at specified locations | Drones grab designated targets

# Scope


DJI Mavic Series
322×242×84 mm (length×width×height)

DJI Phantom Series
Diagonal Distance 350 mm

## System Requirements

Adjustment range | ±10°

## Other requirements

Adjustment accuracy | <0.4°
Working temperature | 0℃-40℃

# Design Requirements

Take off mass | ＜500g
Control dimensions | 2-axis(roll pitch)

Easy and safety operation
Simple structure
System size | ≈220mm×220mm×200mm

not meet location requirement

# Functional Decomposition

Assemble all components; Adjustment; Position; check; Fix spherical pair Disassemble alignment system; End; Start

# Conceptual Design

The goal:
to adjust the laser accurately so that it points to a specific location.

Then, we discuss the solution using the 4-3-5 method and summarized 4 designs.


# Concept 1


# Concept 2


# Concept 3


# Concept 4

## Decision matrices


Comparing the advantages and disadvantages of our design.

Synthesizing everyone's design


In this system，two adIjustment bolts control two degrees of freedom.

## Final design

⚫ Laser movement controlled by robotic arm fixture

⚫ Fixing laser with ball joint

⚫ Gears can be used to control robotic arm deflection

⚫ We can use the bolt thread to control the elongation and shortening of the robot arm

System Requirements

Adjustment range | ±10°
Adjustment accuracy | <0.4°
Take off mass | ＜500g
System size | ≈220mm×220mm×200mm
Working temperature | 0℃-40℃
Control dimensions | 2-axis(roll pitch) | √


This is the design for manufacturability of these two systems. As shown in the figure, different colors represent different materials.

# DFM

System Requirements

Adjustment range | ±10°
Adjustment accuracy | <0.4°
Take off mass | ＜500g | √
System size | ≈220mm×220mm×200mm
Working temperature | 0℃-40℃ | √
Control dimensions | 2-axis(roll pitch) | √

171 mm

220 mm

System Requirements

Adjustment range | ±10°
Adjustment accuracy | <0.4°
Take off mass | ＜500g | √
System size | ≈220mm×220mm×200mm | √
Working temperature | 0℃-40℃ | √
Control dimensions | 2-axis(roll pitch) | √

## Adjustment


## Mechanism

## Fixing Mechanism

## Adjustment Mechanism

## Adjustment Mechanism


Adjustment Bolts

External Retaining Ring

Positioning Flakes

Threaded Nut

Supporting Parts

Platform

Positioning Flake

Sleeve Spring

Standard Key

Worm Gear

Ball Bearings
Spacers

Worm

Threaded Bearing Cover

Lock Nut

Peel Shim

Cushioning Washers & Steel Washers

Rail Nuts and Bolts

# Sleeve Parts


Screws

Sleeve

Supporting Parts
Cushioning Washers

Steel Washers

# Fixing Mechanism


Laser Pen

Laser Pen Base

Steel Threaded Ball
Locking Structure
Platform | Threaded Bolt

# Ball Joint

## Movement Range


## Adjustment Accuracy


Height from the Rod to the Ball Joint (H): 95 mm Expected adjustment angle of laser pen: 10°
Angle range of the system:30 °

Radius from the base center to the pen (L): 140 mm Radius of laser pen center (R): 16.75 mm
Radius range of the system: 17.35 mm

H

R

Part A

Part B

L

Pitch of the Higher Adjusting Bolt: 2mm
Minimum Adjustment Length of R: 2mm×(4°/360°)=0.0222mm

Minimum Adjustment Angle of Bolt:

θ1 = 10° − arctan(

16.75−0.0222
95

) = 0.0136°

θ2 = arctan(

0.0222
95

) = 0.0134°

Because the power of this structure is hand, it’s hard to calculate the accuracy of this system. Here we assume the minimum adjustment angle of hand is 4°.

Part A

## Adjustment Accuracy

θ1 = arcsin 0.547; θ2 = 10° − arctan(; θ3 = arcsin 0.430; Part B; Base Center; Sleeve Center

Speed Ratio: 20:1
Angle per Pitch of the Worm Gear: 360°/20=18°
Worm Gear Minimum Rotation angle: 18°×(4°/360°)=0.2°
Adjustment Angle of the Lower Gear: 0.18°
Minimum Adjustment Angle of Worm Gear:

System Requirements

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

## Movement Range


m=(L+b).*cos(a);
n=(L+b).*sin(a);
C=acos(H/((

m

-L)^2+n^2+H^2)^0.5);
L=140 ，H=95
H

L

x

z

y

L + b

C

a

(0,0,0)

(m, n, H)

(L,0,0)

(L,0,H)

Part of the matlab code
m=(140+B).*cos(A/180*pi);
n=(140+B).*sin(A/180*pi);
k=m

-140;

C=acos(95./sqrt(k.*k+n.*n+95^2))*180/pi; C=real(C);

Minimum Adjustment Length of R: 2mm×(4°/360°)=0.0222mm Worm Gear Minimum Rotation angle: 18°×(4°/360°)=0.2° Angle range of the system:30 °
Radius range of the system: 17.35 mm

Part of the MATLAB code
a=linspace(-30,30,301);
b=linspace(-17.35,17.35,1564); [A,B] = meshgrid(a,b);

## Movement Range


Draw the relationship between input a, b and output m, n, c in the form of image in MATLAB

System Requirements

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


Peel Shim

Positioning Flake


Threaded Bearing Cover

Bearings

Gasket


Bolts

Sleeve

Steel Washer

Cushioning Washer

Q&A

Thanks for watching.

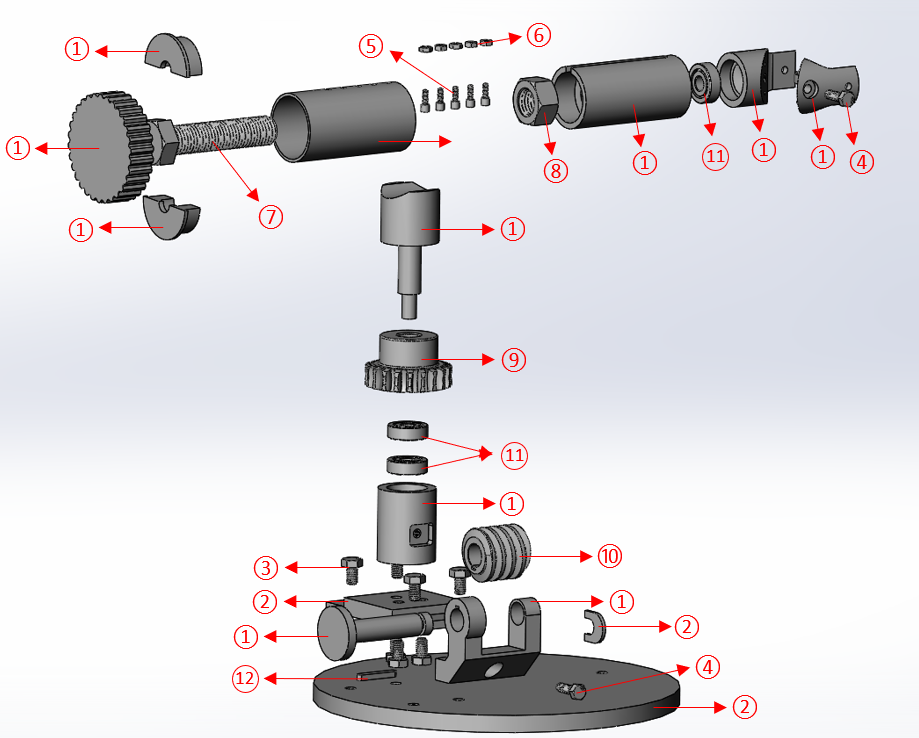
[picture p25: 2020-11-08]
Prototype 4/批注 2020-03-14 201423.png

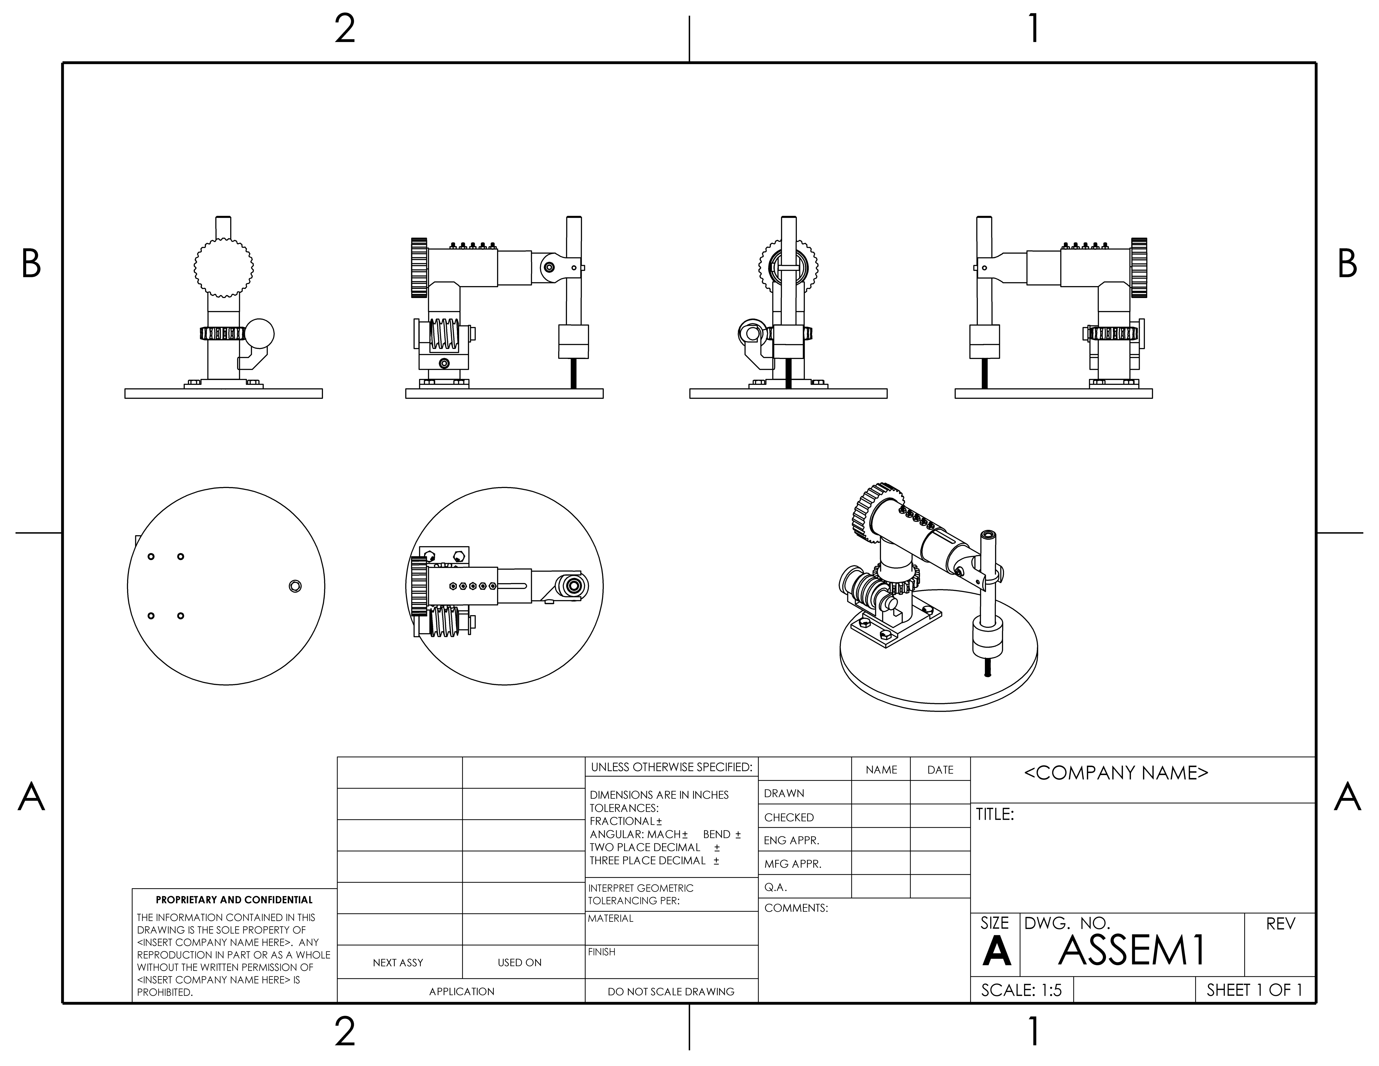
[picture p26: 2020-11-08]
Prototype 4/Assem1.JPG

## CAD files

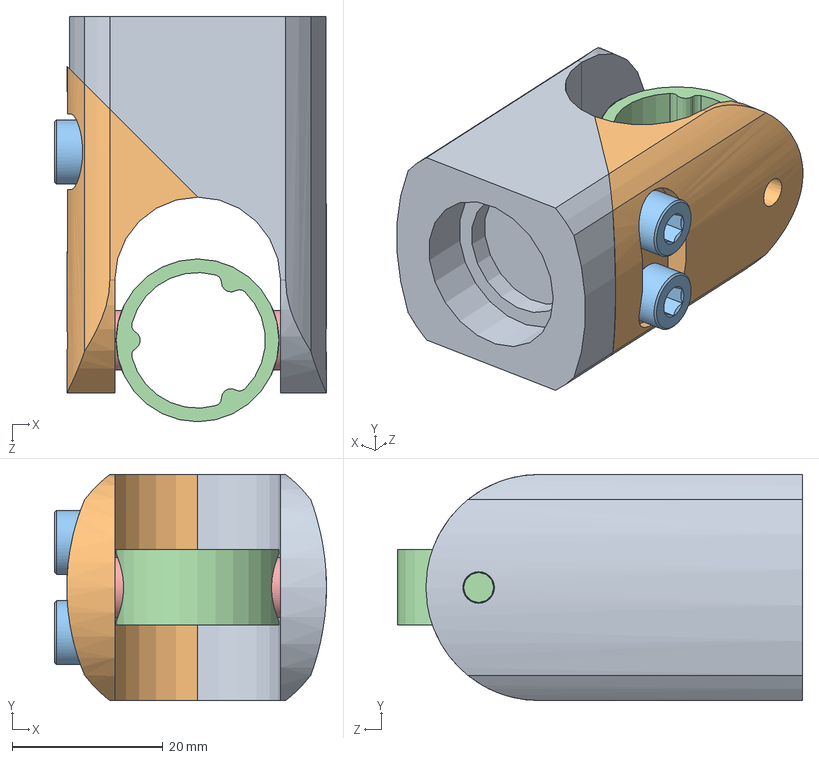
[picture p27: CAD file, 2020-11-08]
Prototype 4/Assem3.SLDASM
36.1 x 30.0 x 53.8 mm
Supporting Part for Sleeve 1
Supporting Part for Sleeve 2
Screw for Supporting Part x 2
Sleeve
Cushioning Washer x 2
Steel Washer x 2

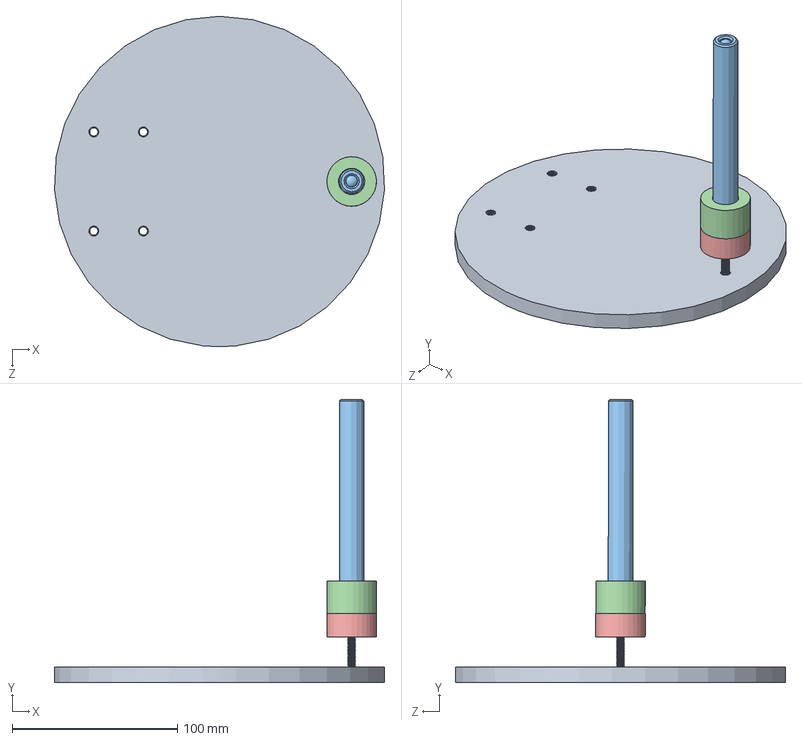
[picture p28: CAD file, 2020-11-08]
Prototype 4/Assem4.SLDASM
199.7 x 171.5 x 200.0 mm
底板
球关节
激光笔
激光笔底座
球关节螺帽
球关节固定螺栓

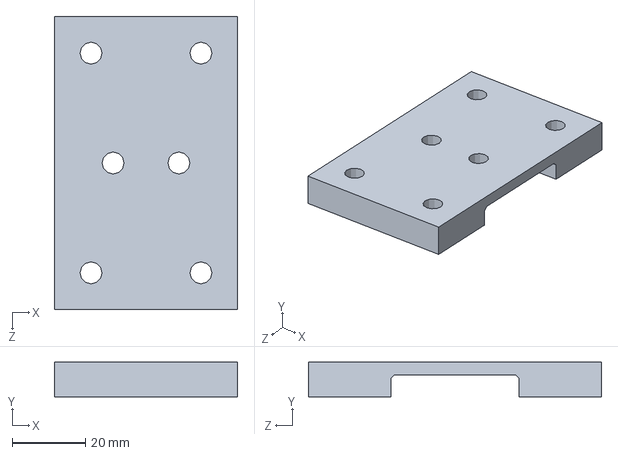
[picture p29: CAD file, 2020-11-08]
Prototype 4/Base.SLDPRT
50.0 x 9.50 x 80.0 mm

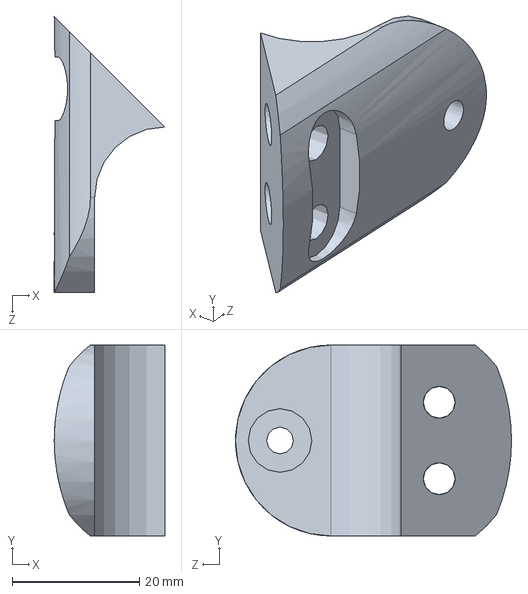
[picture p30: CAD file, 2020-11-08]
Prototype 4/Supporting Part for Sleeve 2.SLDPRT
17.4 x 30.0 x 43.4 mm

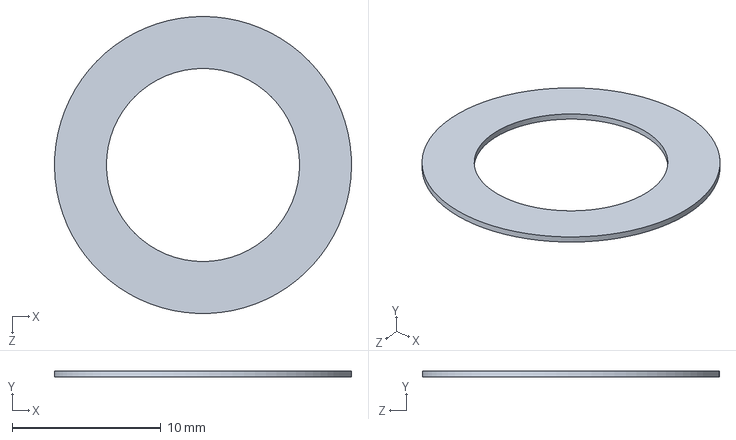
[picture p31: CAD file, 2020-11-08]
Prototype 4/Peel Shim.SLDPRT
20.0 x 0.4 x 20.0 mm

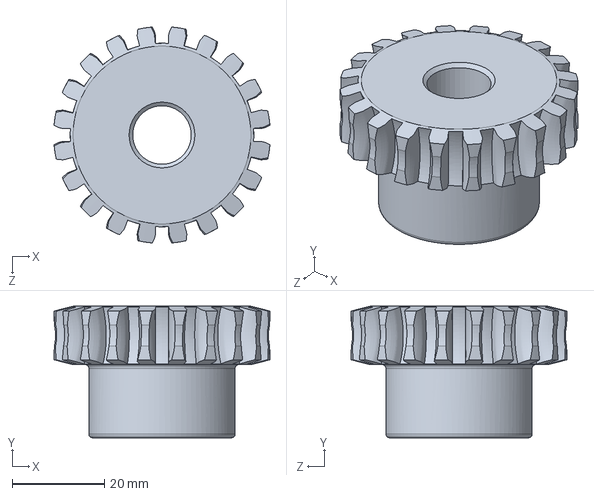
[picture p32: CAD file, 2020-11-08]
Prototype 4/Worm Gear.SLDPRT
46.9 x 28.6 x 46.9 mm

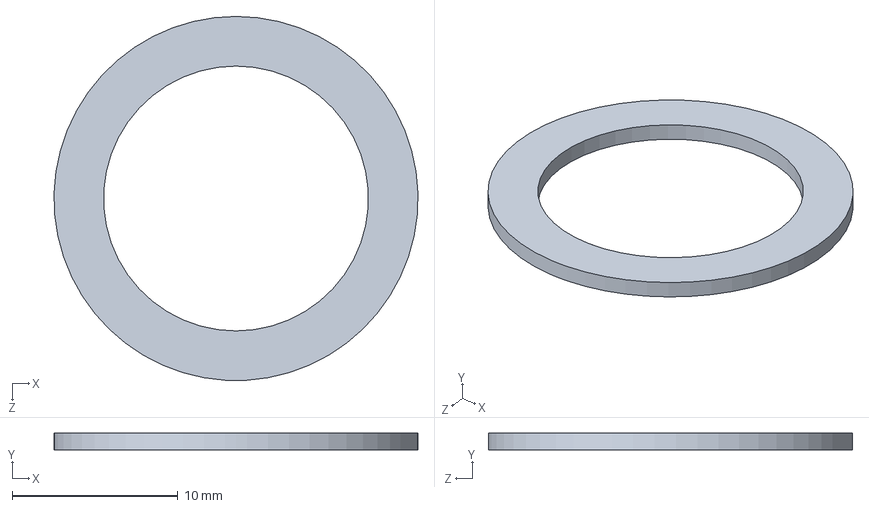
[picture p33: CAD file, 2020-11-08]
Prototype 4/Bearing Outer Spacer.SLDPRT
22.0 x 1.00 x 22.0 mm

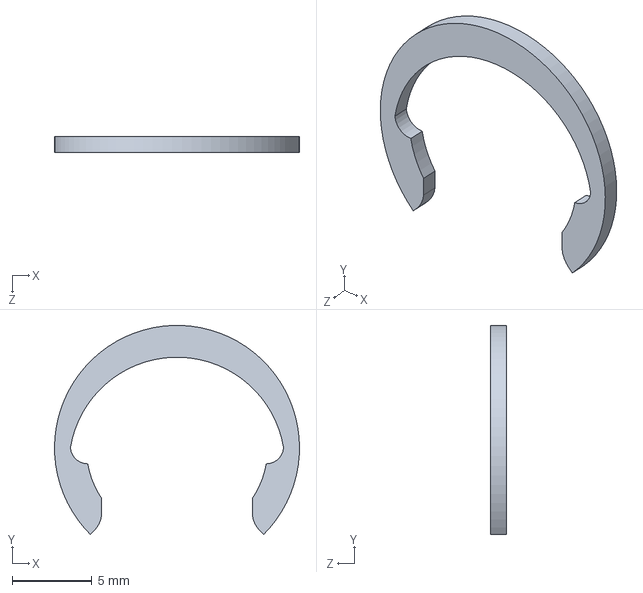
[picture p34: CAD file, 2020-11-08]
Prototype 4/Retaining Ring for Worm.SLDPRT
15.4 x 13.1 x 1.00 mm

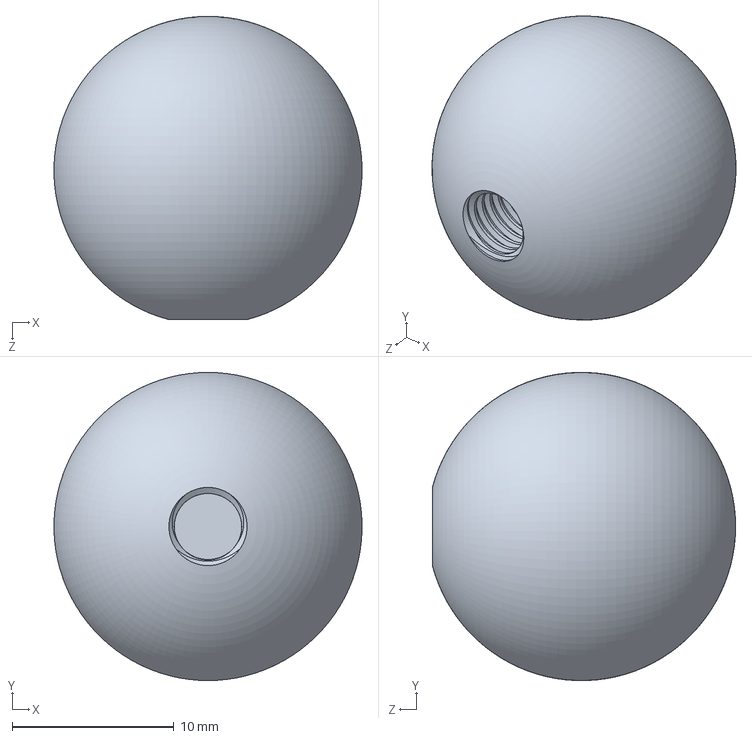
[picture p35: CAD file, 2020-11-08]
Prototype 4/Threaded Steel Ball.SLDPRT
19.0 x 19.0 x 18.7 mm

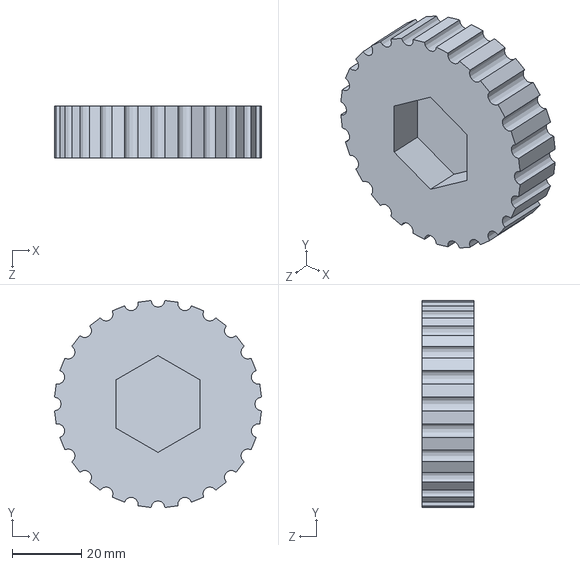
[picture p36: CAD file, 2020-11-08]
Prototype 4/Adjustment Knob.SLDPRT
59.9 x 59.9 x 15.0 mm

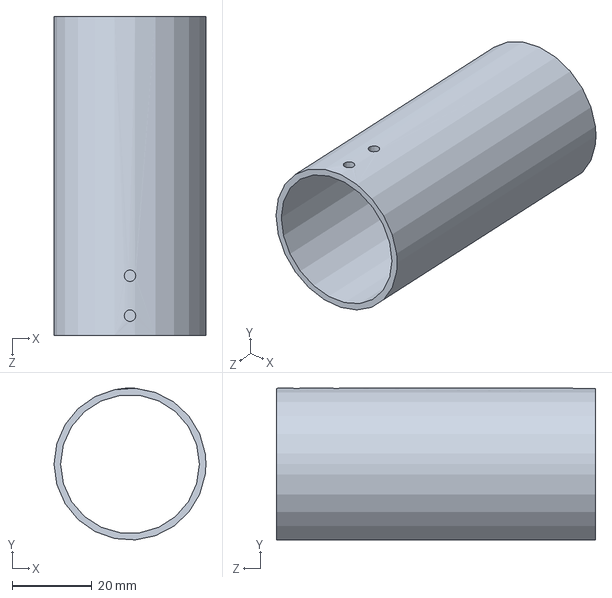
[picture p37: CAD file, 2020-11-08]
Prototype 4/Shell.SLDPRT
38.1 x 38.1 x 80.0 mm

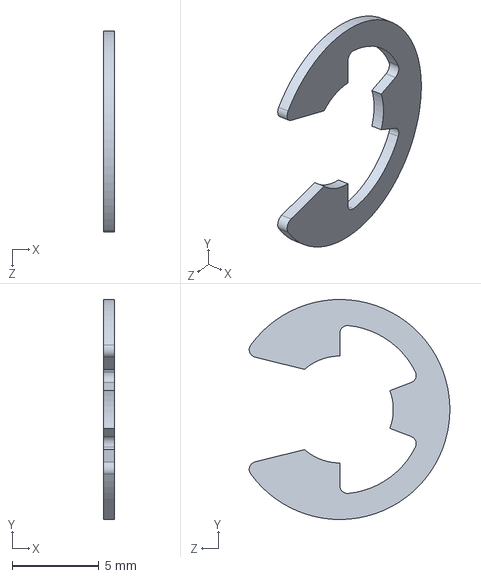
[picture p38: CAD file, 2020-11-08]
Prototype 4/External Retaining Rings.SLDPRT
0.635 x 12.7 x 11.6 mm

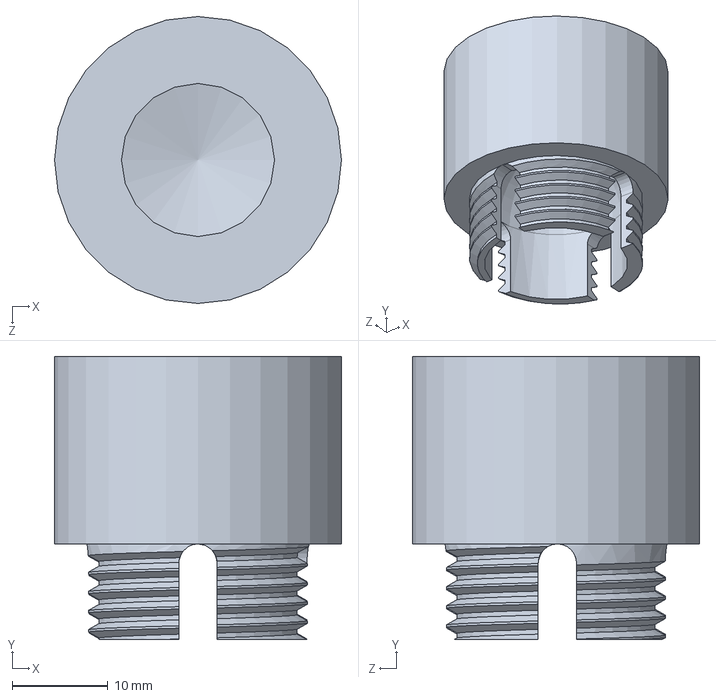
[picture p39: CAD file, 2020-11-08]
Prototype 4/Laser Pen Base.SLDPRT
30.0 x 29.6 x 30.0 mm

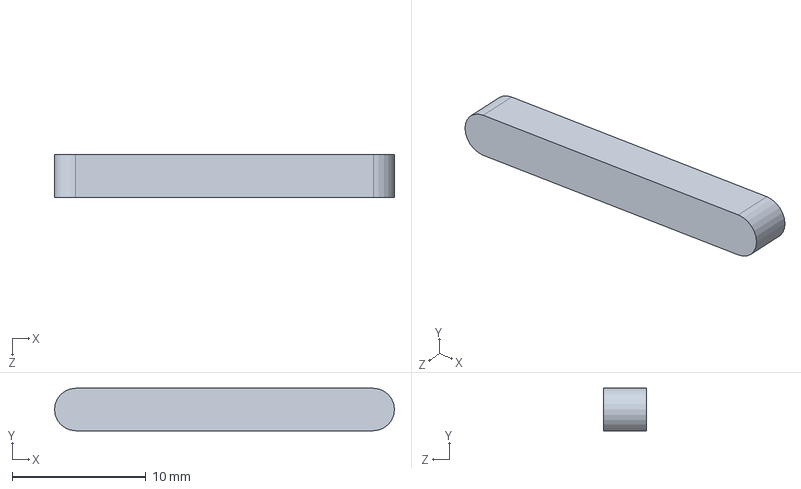
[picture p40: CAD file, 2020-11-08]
Prototype 4/Standard Key.SLDPRT
25.4 x 3.17 x 3.17 mm

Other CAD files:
Prototype 4/Ball Bearing.SLDPRT
Prototype 4/Bearing Inner Spacer.SLDPRT
Prototype 4/Worm.SLDPRT
Prototype 4/Base Adjustment Rod.SLDPRT
Prototype 1/Assem.SLDASM
Prototype 1/固定底座.SLDPRT
Prototype 1/底板.SLDPRT
Prototype 1/控制杆.SLDPRT
Prototype 1/激光底座.SLDPRT
Prototype 1/激光笔.SLDPRT
Prototype 1/激光笔定位器.SLDPRT
Prototype 1/第一连杆.SLDPRT
Prototype 1/第三连杆.SLDPRT
Prototype 1/第二连杆.SLDPRT
Prototype 1/螺帽.SLDPRT
Prototype 2/Assem.SLDASM
Prototype 2/固定底座 1.SLDPRT
Prototype 2/固定底座.SLDPRT
Prototype 2/套筒.SLDPRT
Prototype 2/套筒组件.SLDPRT
Prototype 2/定位片.SLDPRT
Prototype 2/底座定位片.SLDPRT
Prototype 2/底座调整螺栓.SLDPRT
Prototype 2/底板.SLDPRT
Prototype 2/激光底座.SLDPRT
Prototype 2/激光笔.SLDPRT
Prototype 2/第一连杆.SLDPRT
Prototype 2/螺帽.SLDPRT
Prototype 2/调整螺栓.SLDPRT
Prototype 3/Assem.SLDASM
Prototype 3/Assem12.SLDASM
Prototype 3/Assem2.SLDASM
Prototype 3/固定底座 1.SLDDRW
Prototype 3/固定底座 1.SLDPRT
Prototype 3/固定底座.SLDDRW
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

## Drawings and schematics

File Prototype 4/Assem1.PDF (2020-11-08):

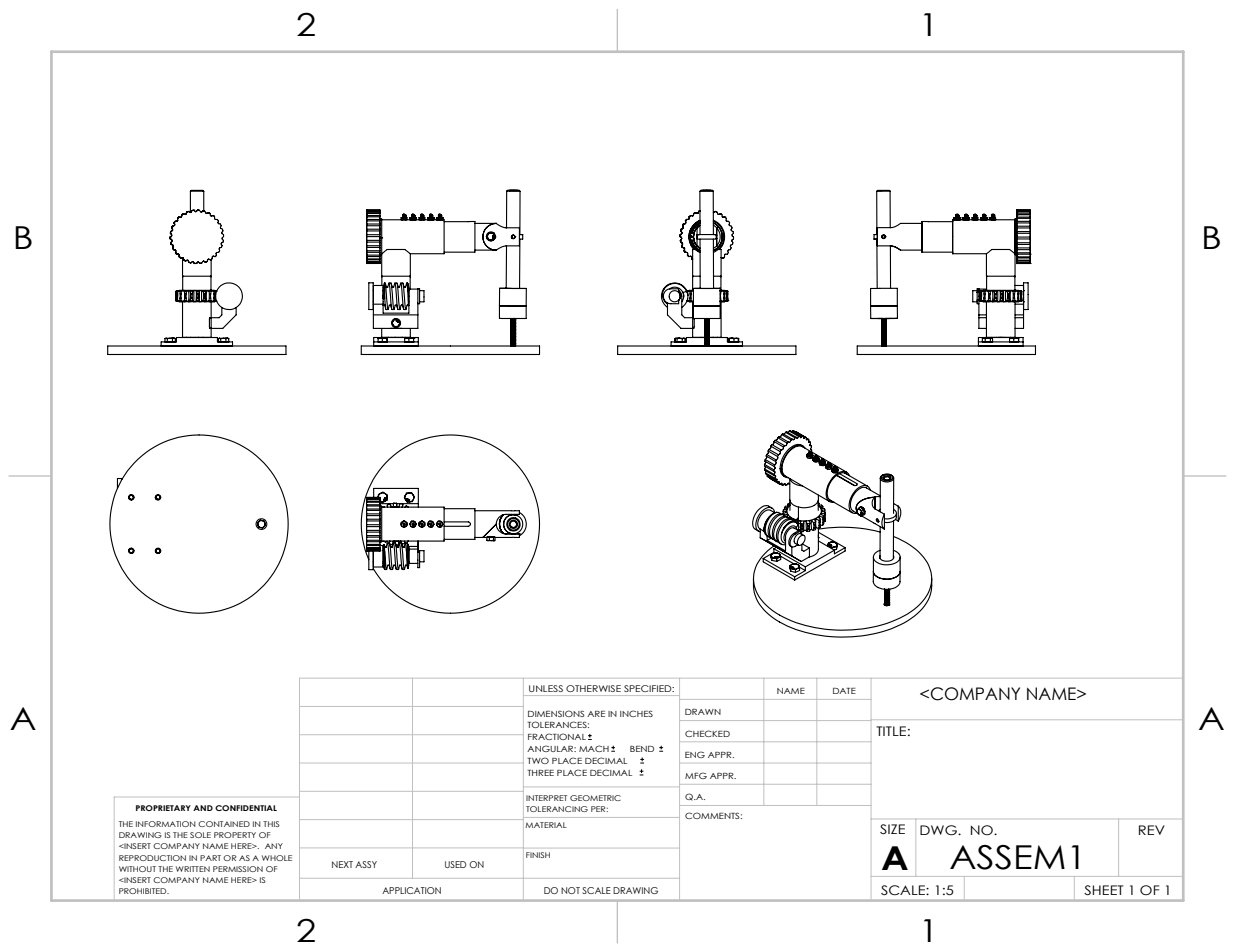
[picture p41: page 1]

UNLESS OTHERWISE SPECIFIED: | | NAME | DATE | <COMPANY NAME>

DIMENSIONS ARE IN INCHES TOLERANCES: FRACTIONAL ANGULAR: MACH BEND TWO PLACE DECIMAL THREE PLACE DECIMAL | DRAWN

CHECKED | | | TITLE:

ENG APPR.
MFG APPR.

INTERPRET GEOMETRIC TOLERANCING PER: | Q.A.

PROPRIETARY AND CONFIDENTIAL
THE INFORMATION CONTAINED IN THIS
DRAWING IS THE SOLE PROPERTY OF
<INSERT COMPANY NAME HERE>. ANY
REPRODUCTION IN PART OR AS A WHOLE
WITHOUT THE WRITTEN PERMISSION OF
<INSERT COMPANY NAME HERE> IS
PROHIBITED.

USED ON | MATERIAL | | SIZE A | DWG. NO. ASSEM1 | REV

NEXT ASSY | | FINISH

APPLICATION | DO NOT SCALE DRAWING | | SCALE: 1:5 | | SHEET 1 OF 1
